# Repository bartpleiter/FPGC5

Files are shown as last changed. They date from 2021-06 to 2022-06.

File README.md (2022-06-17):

# FPGC5

My big project, basically started in July 2019 as FPGC3 (versions 1 and 2 do not count). Project exists to learn more about the fundamentals of computers and to improve my Verilog skills, while also designing my own "environment" (PCB, Compilers, OS, etc.) around it.

FPGC is a completely self designed computer, implemented in an EP4CE15 FPGA.

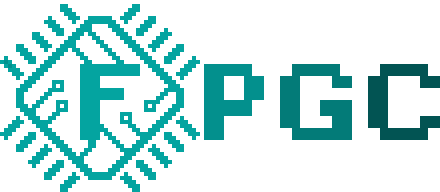
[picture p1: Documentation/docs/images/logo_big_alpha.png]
FPGC Logo (https://www.b4rt.nl/fpgc5/)


[Project Wiki](https://www.b4rt.nl/fpgc5/) (not fully up to date, but contains a lot of info)

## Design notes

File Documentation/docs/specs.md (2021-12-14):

# Specifications
These are the current specifications of the FPGC5:

- 50MHz CPU clock   
- 25MHz or 14MHz main GPU clock (depending on HDMI or NTSC being selected)
- 16MiB external SPI flash (QSPI with continous read mode) @ 25MHz. 32bit addresses (so not byte addressable!!!). Used as ROM, but has option to switch to direct access where it is connected to an SPI bus in the Memory Unit (allows for SPI flashing)
- 32MiB SDRAM @ 100MHz. 32bit addresses. Readable and writable. Used as main memory
- ~16.4KiB VRAM (SRAM). Combination of 32, 8 and 9bit addresses (three seperate modules for pixel data, tile indexes and sprites)
- 2KiB internal ROM for the Bootloader. 32bit addresses
- 4.125KiB Hardware Stack (SRAM). 32bit addresses
- 16 32bit registers, of which 15 are General Purpose
- 32bit instructions
- 27bit program counter for a possible address space of 0.5GiB at 32bit
- 320x200 video output (sent over 640x480 HDMI or 240P NTSC composite) with 256 colors
- Two layers of 8x8 Tiles of which one layer (background) has horizontal hardware scrolling support
- (currently not working anymore) One Sprite layer with support for 64 Sprites. Max 16 Sprites per horizontal line (double the amount of the NES!)
- Memory mapped I/O
- Three One Shot (OS) timers
- PS/2 Keyboard support
- UART and power over USB
- 4 GPI and 4 GPO pins (will become 8 true GPIO pins eventually)
- I2S DAC for future APU
- 2 USB host ports with FAT(12/16/32) file system support using a CH376T controller over SPI
- Ethernet using W5500 over SPI
- 8 interrupts, of which 4 normal interrupts (currently attached to two OS timers, UART RX and the frameDrawn signal of the FSX2), and 4 extended interrupts (currently attached to the PS/2 controller, a third OS timer and nothing for now)

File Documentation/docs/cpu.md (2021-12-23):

# CPU (B322)
The B322 (B4rt 32 bit processor v2) executes instructions from memory with the program counter as address. It is a 32 bit RISC CPU implementing the self designed B322 instruction set.

## B322 ISA
The B322 instruction set architecture is a RISC architecture.
Each instruction is 32 bits and can be one of the following instructions:
``` text
         |31|30|29|28|27|26|25|24|23|22|21|20|19|18|17|16|15|14|13|12|11|10|09|08|07|06|05|04|03|02|01|00|
----------------------------------------------------------------------------------------------------------
1 HALT     1  1  1  1| 1  1  1  1  1  1  1  1  1  1  1  1  1  1  1  1  1  1  1  1  1  1  1  1  1  1  1  1
2 READ     1  1  1  0||----------------16 BIT CONSTANT---------------||--A REG---| x  x |N||I||--D REG---|
3 WRITE    1  1  0  1||----------------16 BIT CONSTANT---------------||--A REG---||--B REG---| x  x  x |N|
4 COPY     1  1  0  0||----------------16 BIT CONSTANT---------------||--A REG---||--B REG---| x  x  x |N|
5 PUSH     1  0  1  1| x  x  x  x  x  x  x  x  x  x  x  x  x  x  x  x  x  x  x  x |--B REG---| x  x  x  x
6 POP      1  0  1  0| 0  0  0  x  x  x  x  x  x  x  x  x  x  x  x  x  x  x  x  x  x  x  x  x |--D REG---|
7 JUMP     1  0  0  1||--------------------------------27 BIT CONSTANT--------------------------------||O|
8 JUMPR    1  0  0  0||----------------16 BIT CONSTANT---------------| x  x  x  x |--B REG---| x  x  x |O|
9 LOAD     0  1  1  1||----------------16 BIT CONSTANT---------------| x  x  x |H| x  x  x  x |--D REG---|
10 BEQ     0  1  1  0||----------------16 BIT CONSTANT---------------||--A REG---||--B REG---| x  x  x  x
11 BNE     0  1  0  1||----------------16 BIT CONSTANT---------------||--A REG---||--B REG---| x  x  x  x
12 BGT     0  1  0  0||----------------16 BIT CONSTANT---------------||--A REG---||--B REG---| x  x  x  S
13 BGE     0  0  1  1||----------------16 BIT CONSTANT---------------||--A REG---||--B REG---| x  x  x  S
14 SAVPC   0  0  1  0| 0  0  0  x  x  x  x  x  x  x  x  x  x  x  x  x  x  x  x  x  x  x  x  x |--D REG---|
15 RETI    0  0  0  1| x  x  x  x  x  x  x  x  x  x  x  x  x  x  x  x  x  x  x  x  x  x  x  x  x  x  x  x
16 ARITH   0  0  0  0||C||--OPCODE--||--------11 BIT CONSTANT--------||--A REG---||--B REG---||--D REG---|
```

1.  `HALT`:   Will prevent the CPU to go to the next instruction by jumping to the same address. Can be interrupted.
2.  `READ`:   If !I, read from memory at address in AREG + 16 bit offset. If N == 1, then do - offset instead. If I, read interrupt ID. In both cases of I: store value in DREG.
3.  `WRITE`:  Write value from BREG to memory at address stored in AREG + 16 bit offset. If N == 1, then do - offset instead.
4.  `COPY`:   Read memory from address in AREG + 16 bit offset, then write result to memory at address in BREG + 16 bit offset. If N == 1, then do - offset instead.
7.  `PUSH`:   Pushes value in AREG to stack.
8.  `POP`:    Pops value from stack into DREG.
9.  `JUMP`:   Set PC to 27 bit constant if O is 0. If O is 1, then add the 27 bit constant to PC. 
9.  `JUMR`:   Set PC to DREG + 16 bit constant if O is 0. If O is 1, then add the value from DREG + 16 bit constant to PC. 
5.  `LOAD`:   Write 16 bit constant to DREG. If H is 0, then write data to lowest 16 bits and set highest 16 bits to 0. If H is 1, then write data to highest 16 bits and ignore lowest 16 bits.
11. `BEQ`:    If AREG == BREG, add 16 bit constant to PC.
12. `BNE`:    If AREG != BREG, add 16 bit constant to PC.
13. `BGT`:    If AREG >  BREG, add 16 bit constant to PC. Signed comparison if S.
14. `BGE`:    If AREG >= BREG, add 16 bit constant to PC. Signed comparison if S.
15. `SAVPC`:  Save current PC to DREG.
16. `RETI`:   Restore PC after interrupt and re-enable interrupts.
10. `ARITH`:  Execute operation specified by OPCODE on AREG and BREG. Write result to DREG. Use 11-bit constant in stead of BREG if C is 1.

## Components
The CPU consists out of the following components:

### Timer
Handles the timing of the CPU phases.

The Timer creates four phases for the CPU to execute each instruction:

1. fetch: Get instruction from memory
2. getRegs: Get register values from register bank
3. readMem: Read memory from address
4. writeBack: Write result back to register bank or memory and change the program counter

The fetch, readMem and writeBack phase can take multiple clock cycles because of the memory timings.

<figure>
    timer waveform
    <figcaption>Timer waveform. Running instructions from SDRAM (outdated simulation!).</figcaption>
</figure>

### Instruction Decoder
Splits the 32 bits of each instructions using combinational logic.
These parts are then connected to various other components of the CPU. 

### Register bank
Contains 16 registers which are all 32 bit wide. Aside from `R0` which is always zero, all registers are basically GP register. However, to maintain some kind of coding consistency, some registers have a special function assigned (though their hardware implementation are the same).

The 16 32 bit registers have the current functions:
``` text
Register|Hardware 	|Assembly	|C
-----------------------------------------------------
R0 		|Always 0	|Always 0	|Always 0
R1 		|GP			|Arg|retval |Very local temp reg
R2 		|GP			|Arg|retval |Ret0
R3 		|GP			|Arg|retval |Ret1
R4 		|GP			|GP			|Arg0
R5 		|GP			|GP			|Arg1
R6 		|GP			|GP			|Arg2
R7 		|GP			|GP			|Arg3
R8 		|GP			|GP			|GP0
R9 		|GP			|GP			|GP1
R10		|GP			|GP			|GP2
R11		|GP			|GP			|Temp
R12		|GP			|GP			|Temp
R13		|GP			|GP			|SP
R14		|GP			|GP			|BP
R15		|GP			|Ret Ptr 	|Ret addr
```
The register bank has two read ports and one write port. Internally on the FPGA, the registers are implemented as two block RAM modules to increase performance and save space. One module contains the highest 16 bits, the other the lowest 16 bits. This made it easy to implement the `LOADHI` instruction.

Note that the program counter is not part of the register bank, as it is a seperate part of the CPU.

### Stack
Stack memory with internal stack pointer. The stack is mostly used in assembly coding for jumping to functions and backing up or restoring registers in interrupt handlers or functions. In combination with the SavPC instruction, one can easily jump to (and return from) functions in assembly (C uses a software stack).

The pointer wraps around in case of a push when the stack is full or in case of a pop when the stack is empty.
The stack is 1024 words deep. The stack pointer and stack memory are not accessible by the rest of the CPU. This and the small size make the stack mostly unusable for the C compiler. For this, a software stack implementation using the 32MiB SDRAM main memory and R13,R14,R15 are used. However, the hardware stack is used to quickly backup and restore all 15 GP registers during an interrupt.

### ALU
Can execute 16 different operations on two 32 bit inputs. Has two flags, which are used for branch instructions. It also has an input flag `skip`. When set, the output of the ALU will just be input B. This is useful for writing values to a register after a `READ`.
The 4 bit opcode can specify the following operations:
``` text
Operation|Opcode|Description
-------------------------
OR        0000   A OR   B
AND       0001   A AND  B
XOR       0010   A XOR  B
ADD       0011   A  +   B
SUB       0100   A  -   B
SHIFTL    0101   A  <<  B
SHIFTR    0110   A  >>  B
MULT      0111   A  *   B (signed!)
NOTA      1000   ~A
```

The remaining seven Opcodes are reserved for future operations.

Internally, the CPU uses flags for executing the branch instructions. Depending on the instruction flags these comparisons can be signed. The flags are not readable by other instructions, because they are not saved in a register:
``` text
Flags
---------
BGA: B is greater than A
BEA: B is equal to A
```

### PC
Handles all program counter related functions like jumps and interrupts.

Every writeBack cycle, the PC is increased by one. In case of a jump, the PC is set to or increased by the jump address, based on the `O` flag of the jump instruction.

The CPU has 8 interrupt pins, of which 4 standard interrupts and 4 extended interrupts (extended has nothing to do with the duration of the interrupt, see it as a pin extension). When a rising edge on one of these pins is detected and interrupts are enabled, interrupts will be disabled, the PC value of the next instruction (this includes the destination address during a jump) will be stored and the set to the value of the interrupt pin (1, 2, 3, or 4, and 2 in case of an extended interrupt). When a RETI instruction is issued, the PC will be restored and interrupts re-enabled. Interrupts are only registered on the rising edge, to prevent the same interrupt from repeating itself when the handler is already done, but the signal is still high. In case of multiple interrupts at the same time, the lowest pin number has the highest priority. Interrupt 1 to 4 have priority over the extended interrupts. A flag for each rising interrupt is stored, even when interrupts are disabled. This causes the interrupt to be delayed until interrupts are enabled again. This way less interrupts are skipped.

For the extended interrupts, the PC will still jump to address 2, but will also set an ID. This way the interrupt handler can check which interrupt was triggered. The ID can be read using the `I` (interrupt) flag in the READ instruction.

### CU
The CU, or control unit, directs all signals to the corresponding components based on the instruction, state and flags. This is done using combinational logic.

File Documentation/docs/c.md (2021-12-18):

# C Compiler

!!! info "TODO"
	Very outdated! now using a C compiler based on SmallerC (written in C)

Using the C compiler it is possible to compile C code to B322 assembly. Using C it is way easier to write code for the FPGC5, although it is less optimized and currently not perfectly stable.

## How the C Compiler works
A C compiler is a very complex piece of software. To prevent having to spend a very long time on writing an instable, slow and unfinished C compiler, I modified an existing C compiler instead. I found a very good and well documented C compiler written in Python (the easiest programming language), called [ShivyC](https://github.com/ShivamSarodia/ShivyC). ShivyC outputs x86_64 assembly code. It has the following stages:

- lexer: reads C file, creates tokens
- preprocessor: handles include statements
- parser: parses tokens and creates an abstract syntax tree
- ILgen: generates Intermediate Language code from the AST
- ASMgen: generates x86_64 code from the IL

To make the compiler output B322 assembly, I (mostly) only needed to adjust the last stage. Luckily, the x86_64 assembly and B322 assembly have much in common in terms of registers and instructions (relatively), so no major modifications to the other stages, which were made with x86_64 in mind, were needed. Some assembly wrapping code is used to set up things like the stack, interrupt handlers and return code.

## Biggest differences between x86_64 and B322 assembly
There are a few big differences between these languages:

### Register sizes
B322 has 16 (15 if you ignore r0 which is always 0) 32 bit registers. x86_64 has multiple variants of its registers for 8, 16, 32 and 64 bit values. I 'fixed' this by forcing the C compiler to only use the 32 bit versions of the registers.

### Byte addressable memory
B322 uses word addressable memory, meaning that each address is 32 bits. x86_64 uses byte addressable memory, so I had to modify the compiler to use 1 address per integer (32 bits) instead of 4.

### Memory access in each instruction
B322 has READ, WRITE and COPY instruction to access memory. All other instructions can only be applied to registers (and in some cases literals). x86_64 can use literals, registers and memory (with offsets and multiplications!!!) for almost all instructions. This is by far the biggest problem I currently have and requires writing cases for almost all possibilities. I started doing this kind of ad hoc and need to spend more time on this to improve stability.

## Stack
C uses a stack. Since the hardware stack of the FPGC5 is too small, has no external pointers and is not addressable, a software stack is used instead. The stack starts at the end of SDRAM at 0x700000 and grows towards 0. The interrupt handlers have a separate (and smaller) stack, starting at 0x7B0000. R14 and R15 are used as base pointer and stack pointer respectively.

Since x86_64 has byte addressable memory, integers (32 bit) are stored with an offset of 4 of each other. The FPGC5 does not have byte addressable memory. This means that chars are stored in 32 bit spaces and therefore have no overflow. This also means that using variables longer that 32 bits (longs) are cutoff at 32 bits. Should not be a big issue, since we only have 27 bits addresses anyways. Worst case, this means that 75% of the stack is unused. While this sounds like a lot, it is currently not a problem because of the relatively huge memory size of 32MiB. Will probably fix it in the future.

## Register mapping
The registers are mapped in the following way:

``` text
x86_64 	| FPGC5
----------------
rax		| r1
rbx 	| r2
rcx 	| r3
rdx 	| r4
rsi 	| r5
rdi 	| r6
r8 		| r8
r9  	| r9
r10 	| r10
r11 	| r11
rbp 	| r14
rsp 	| r15
```
This leaves registers r7, r12 and r13 unused in the FPGC5.
r12 and r13 are currently used as temporary registers for certain assembly instructions, which is sometimes needed/convenient for converting single x86_64 instructions to multiple B322 instructions. For example, in x86_64 you can write a number to the stack at an offset using `mov [rbp-offset] 37`. In B322 you first need to load the literal into a register before using a write instruction. r7 is currently used as temp register for loading the address of global variables during for read/write instructions.

## Assembly wrapper
- Return value of Main() is sent over UART (mainly for testing)
- Initializes stack starting address
- Full context switch for interrupt handlers

## Testing the compiler
To make sure that everything still works after making a change in the compiler, I made a number of test .c files with an expected return value. Using the runCfiles.sh script, you can send compile and send multiple .c files to the FPGC5 and get their return value. So to automatically test all test files, you just have to run `runCfiles.sh test/*.c`. The script automatically compiles, assembles and sends the code over UART to the FPGC5 (so use the UART bootloader for the SPI flash module). When the program is done executing, the FPGC5 will send back the return value, which you can compare. The FPGC5 also resets between each file, because of the UART DTR reset (just like an Arduino).

## Supported and unsupported features
Most basic features like for/while loops are supported, so I will not list everything.

### Supported
- defines (only numbers, no expressions or strings)
- includes (.h files should also contain the code, because no linking). Circular dependencies are allowed. Defines from includes carry over, like real C
- inline assembly (see section inline assembly)
- structs (not fully tested)
- arrays
- pointers
- hex and binary numbers (using 0x and 0b prefixes), also in defines
- bitwise operators (shift, xor, etc.) (bitwise and uses `&&&` as sign!)
- probably some things that I don't use, see ShivyC on Github.

### Unsupported
- floating points
- negative numbers! (the FPGC5 does not do any signed operations)
- division and modulo (use div() and mod() in the math library for this)
- include guards, since this is handled internally inside the compiler (for includes)
- compiling and linking multiple .c files. So libraries should be written entirely in a single .h file
- certain array initializers (like `char a[] = "foo";`)
- complex things like varargs, which I never used anyways
- probably some other things :s

## Interrupt handler
Because of the way interrupts are handled in the assembler, it is required for each main .c file to have the functions (void) int1() int2() int3() and int4(). These can be empty, since the context switch (using the hardware stack) and `reti` are handled by the wrapper.

## Inline assembly
The C compiler supports inline B332 assembly. See the following code for an example:

``` c
int main() 
{
	int a = 7; // should be put into r1 by the compiler

	// backslashes are needed for the lexer, semicolons are needed to keep track of each line
	// comments can be added before the semicolon using //
	ASM("\
		load 4 r2								;\
		add r1 r2 r3 	//adding two regs		;\
		sub r3 1 r1 	//remove one to get 10 	;\
		");

	return a; // should now be 10
}
```
Inline assembly is especially useful for implementing fast functions like copying VRAM tables. It might also be useful for addressing I/O, though this will depend on the situation, since you cannot easily access values from the C code using assembly.

!!! danger
    The compiler does not parse the assembly code, so be very very careful to not mess up the registers. Use `pop` and `push` to back them up!

## Coding style recommendation
Since there is currently no OS, memory (heap) management needs to be done by the programmer. So write at top of program/library which variables are stored at which address. Also, see the Main Memory Map below.

- Some variables can be defined as global variables, which the compiler puts in the Program code (recommended way if possible)
- Libraries have their own heap, and each library should use different addresses within this space
- Use clear function names, and defines with prefixes if necessary, to avoid conflicts
- Use integers for pointers, as they are 32 bit
- Use mostly integers, since these are the same size as a register
- Program code is not different from any other place in memory, and therefore can be easily modified at runtime

### Main Memory Map
This memory map visualizes where what is (or should) be stored where in memory:

``` text
|00|01|02|03|04|05|06|07|08|09|10|11|12|13|14|15|16|17|18|19|20|21|22|23|24|25|26|27|28|29|30|31|
|_______________________________________________________________________________________________|
|-----------------Program Code------------------|Usr Heap|L*|---------Stack---------|Int S*|-R*-|
					 16MiB						   3MiB  1MiB          8MiB         2.75MiB 1.25MiB

L* 		= Library heap, like a map with the currently pressed ps/2 buttons
Int S* 	= Interrupt stack, a separate stack for interrupt handlers
R* 		= Currently unused, reserved for future things

```

## NOTES

Notes that came up while working on BCC:
- the goal of this C compiler is to write code for the FPGC, not to be compliant to anything C related!
- should probably use chars as much as possible, since they are 32 bits in my case and the compiler will align this with memory (might want to typedef tho)
- should optimize the reimplementation of BDOS as much as possible now I have the chance

- includes:
    - all includes should be .c files, there is no linker and everything should be considered as one big C file
    - because no linking and .h files, only the main.c file should include all libraries, so libraries should not include files themselves (main.c should do that for them)
       Might want to add in comments which includes the library needs
    - if there are two functions that call each other (or some kind of loop), you should be able to just add a template function at the top (like a header file does)
    - global variables accessed by libraries should be defined above the #include

- ASM:
    - use this:
    ``` text
    // r2 contains the return value, r4 contains the argument
    int asmReturn(int x)
    {
        int retval = 0;

        asm("load 4 r3\n"
            "add r4 r3 r2    ;adding two regs\n"
            "sub r2 1 r2     ;remove one to get 10\n"
            "write -4 r14 r2 ;write to stack to return");

        return retval;
    }
    ```

- comparison is signed by default. For unsigned comparison, cast both expressions to (unsigned int) -> forces bge/bgt instead of bges/bgts

- could optimize for speed by converting more basic functions to ASM
    - also, the ch376 asm functions could use a COPY instruction instead of a read followed by write

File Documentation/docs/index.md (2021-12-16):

# Welcome to the FPGC Wiki!

FPGC Logo (https://www.github.com/b4rt-dev/fpgc5)

!!! danger
    A lot of the documentation is probably outdated

For more details, use the navigation menu.

## What it is
The FPGC5 (Field Programmable Game Console/Computer v5) is my big hobby project, built around a completely self designed SoC (System on a Chip) with my own CPU, GPU and Memory Unit, all implemented on an FPGA. The goal of this project is to understand how computers actually work, by making one myself. This is achieved by starting from scratch and adding a layer of complexity iteratively. As of writing it has a simple OS and C compiler.

Originally, the goal of this project, which started in 2017 when I bought my first FPGA, was to design a simple game console for an FPGA (hence the name FPGC). Eventually this idea shifted more towards creating an entire computer with the capabilities of a game console. Now this is shifting even more to a computer rather than game console (the third PCB doesn't even have a game controller connector anymore).

To give a general idea: The FPGC is kind of a Raspberry Pi, but with the performance of a Commodore 64, the graphics of a NES, and some "less retro" features like HDMI, USB host, Ethernet, 32MiB SDRAM and a 32 bit architecture.

The main components of the FPGC5 consist of my 32 bit CPU (B322), my tile/sprite based GPU (FSX3) and my Memory Unit (MU) that handles many different types of memory and I/O. No audio engine yet, though I do have an I2S DAC on the PCB.

Aside from the FPGA hardware, this project also contains other software projects built for the FPGC, like an assembler, C compiler (both cross-compile from Linux and self compile from BDOS), Operating System (BDOS), software libraries, programmer, example code like a webserver and a wget implementation, and more.

For this project I also designed an I/O board PCB.

## What it can do
Basically, the FPGC5 can run code, compute things, play games, output video (over NTSC or HDMI), and can interact with certain peripherals using for example GPIO, SPI or UART. It also has two USB host port for mass storage (required for BDOS) and something else, a PS/2 port for a keyboard (although an USB keyboard can also be used) and an Ethernet port for networking. It has 32MiB SDRAM and the program code is very quickly loaded from SPI flash or USB UART into SDRAM on boot. The board is powered from a single micro USB port, with UART capabilities for in-system programming.

As for performance, you should think of a computer from the 80's, but with 32MiB SDRAM, multiple gigabytes of (slow, you want to use buffers) mass storage using USB, and a (not so efficient) 32 bit CPU running at 50MHz. The GPU creates a 320x200 video output which is currently sent over a 640x480 HDMI signal and a composite NTSC signal for my CRT TV (output can be selected using a switch). The graphics are comparable to a NES (currently sprites need to be reimplemented for the HDMI/Composite output).

## Project hardware and software
The target FPGA is an Altera Cyclone IV EP4CE15 (the EP4CE6 has too little I/O, memory and logic gates). The development board used in this project is the [Cyclone IV EP4CE15 Core Board with 32MiB SDRAM from QMtech](https://www.aliexpress.com/i/32949281189.html). This board is plugged into my I/O board PCB, which provides all I/O and power.

All hardware designs are written in Verilog. Iverilog and GTKwave are used to simulate these hardware designs before writing the design to the FPGA using Quartus Prime (Lite).

Most scripts are written in Python 3 (or bash for some simple tasks), except for the C compiler, which is written in C. The cross-assembler is written in Python, and an assembler written in C is being made to run on BDOS. The assembler assembles a self designed assembly language, and the C compiler compiles C to this assembly language.

Sublime Text 3 is used as text editor/IDE, with some handy build scripts to speed up the development and to quickly send code to the FPGC.

There are also scripts that allow sending files and programs directly to BDOS over the network.

## Structure of project files
The general structure of this project:
``` text
FPGC5
├── Assembler           // Assembler (in Python) and assembly code files
├── BCC                 // C compiler project, also contains programs and OS
├── Documentation       // Documentation website project
├── Graphics            // Scripts for graphics related stuff
├── MidiConverter       // Scripts to convert .mid files into audio asm code
├── PCB                 // PCB KiCad source files
├── Programmer          // Scripts for programming the FPGC5
├── Quartus             // Quartus project files
├── SublimeText3        // Project build scripts for Sublime Text 3
└── Verilog             // Verilog source files
    ├── memory          // Memory init related files
    ├── modules         // Hardware modules
    ├── output          // Simulation output
    └── testbench       // Simulation testbench
```

## Project Links
- [Github Repository](https://www.github.com/b4rt-dev/FPGC5)
- [Gogs Mirror](https://www.b4rt.nl/git/bart/FPGC5-mirror)
- [Documentation (this site)](https://www.b4rt.nl/fpgc)

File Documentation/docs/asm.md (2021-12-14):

# Assembler for B322

!!! info
    This is both outdated (no .code/.data/.rdata/.bss, no --bdos or --os, etc.) and only applies to the cross-assembler written in Python!

The basic way to write code for the B322 is by using the B322 assembly language. Using the assembly language you can write the most optimal code, although it might not be the best way for big or complex programs. For high performance functions like copying VRAM tables, assembly is a good solution. For big and complex software, it is better to write the code in C. The C compiler compiles to this assembly language.

The assembler compiles the assembly code to 32 bit machine instructions. The input file is currently code.asm, and the output is printed to stdout.

## Line types
Each line is parsed on its own. There are five types of lines:

- Includes
- Comments
- Defines
- Labels
- Instructions

### Includes
By adding an \`include namehere.asm statement, it is possible to add code from other files, like libraries. The way this works in the assembler is by just adding all lines of that file to the code, while recursively importing includes from other files. The assembler makes sure that the same file is never included more than one time. The path to the file is relative to the assembler.

### Comments
Comments can be added by using the ';' character. For each line, only the part until the first ';' occurrence will be used by the assembler. This means that anything can be written after the ';'. This all does not go for .ds lines. They must not have any comments. This way it is not needed to use escape characters in the strings

### Defines
Defines are the first type of lines that are processed by the assembler. A define line should have the following structure:
``` asm
define TEXTTOREPLACE = textToReplaceWith
```
It is not necessary for 'define' to be in lower caps and 'TEXTTOREPLACE' to be in all caps. However, it is recommended to do so as a coding style. Also, it is recommended to place all define statements at the top of the file before the first instruction or label.
The define statement is used as a textual replacement. This means that no values or anything will be processed or converted during the processing of the define statements. This also means that is not smart to replace text that are used in instructions or labels.
Furthermore, 'TEXTTOREPLACE' should be unique for each define statement. If not, the assembler will complain.

### Labels
Labels can be used to get the address in the assembled code of the instruction below the label. To define a label, one should use the following syntax:
``` asm
LabelName:
```
LabelName can consist of any character, including numbers and special characters, as long as it is just one word (so no spaces, newlines etc.) The label must end with a ':' character. On the same line after this ':' character, no other text is allowed, except comments.

A label can be referenced by using the LabelName in certain instructions at specific places (see section Instructions).
The assembler will eventually compute the address of the label and replace all LabelName occurrences with this address. One can make forward and backward references, which means that one does not have to define a label earlier in the code before referencing, as long as the label is defined somewhere in the code.

Each program should at least contain the following labels (if not, the assembler will complain):
``` asm
Main: ; this is where the CPU will initially jump to
Int1: ; interrupt 1 handler
Int2: ; interrupt 2 handler
Int3: ; interrupt 3 handler
Int4: ; interrupt 4 handler
```

It is recommended to start each label with a capital letter, however this is not mandatory.
One should not use two labels directly after each other without any instruction in between (the compiler will now insert a NOP in between the labels if this happens, since the C compiler sometimes creates this issue), and one should not use a label at the end of the file. The assembler will complain if the latter happens.
When two identical labels are defined, the assembler will complain.
It does not matter if a label is never referenced.
However, it does matter when a reference is made to a label that is not defined. In that case the assembler will complain.
Each of the interrupt handler labels should 'end' with a reti instruction, otherwise the CPU will not return from the interrupt and could highly probably softlock. However, this is not checked by the assembler.

### Instructions
The instructions are the lines that will be assembled into machine code. Each instruction has its own format with the following description:
``` text
Instr   | Arg1  | Arg2 | Arg3   || Description
================================||=====================================================================
HALT    |       |       |       || Halts CPU by jumping to the current address
READ    | C16   | R     | R     || Read from addr in Arg2 with 16 bit offset*** from Arg1. Write to Arg3
WRITE   | C16   | R     | R     || Write to addr in Arg2 with 16 bit offset*** from Arg1. Data to write is in Arg3
COPY    | C16   | R     | R     || Copy from address in Arg2 to addr in Arg3 with 16 bit offset*** from Arg1
PUSH    | R     |       |       || Push Arg1 to stack
POP     | R     |       |       || Pop from stack to Arg1
JUMP    | L/C27 |       |       || Jump to Label or 27 bit constant in Arg1
JUMPO   | C27   |       |       || Jump to 27 bit constant offset in Arg1
JUMPR   | C16   | R     |       || Jump to Arg2 with 16 bit offset in Arg1
JUMPRO  | C16   | R     |       || Jump to offset in Arg2 with 16 bit offset in Arg1
LOAD    | C16   | R     |       || Load 16 bit constant from Arg1 into Arg2
LOADHI  | C16   | R     |       || Load 16 bit constant from Arg1 into highest 16 bits of Arg2
BEQ     | R     | R     | C16   || If Arg1 == Arg2, jump to 16 bit offset in Arg3
BNE     | R     | R     | C16   || If Arg1 != Arg2, jump to 16 bit offset in Arg3
BGT     | R     | R     | C16   || If Arg1 >  Arg2, jump to 16 bit offset in Arg3
BGE     | R     | R     | C16   || If Arg1 >= Arg2, jump to 16 bit offset in Arg3
BGTS    | R     | R     | C16   || (signed) If Arg1 >  Arg2, jump to 16 bit offset in Arg3
BGES    | R     | R     | C16   || (signed) If Arg1 >= Arg2, jump to 16 bit offset in Arg3
SAVPC   | R     |       |       || Save program counter to Arg1
RETI    |       |       |       || Return from interrupt
OR      | R     | C11/R | R     || Compute Arg1 OR  Arg2, write result to Arg3
AND     | R     | C11/R | R     || Compute Arg1 AND Arg2, write result to Arg3
XOR     | R     | C11/R | R     || Compute Arg1 XOR Arg2, write result to Arg3
ADD     | R     | C11/R | R     || Compute Arg1 +   Arg2, write result to Arg3
SUB     | R     | C11/R | R     || Compute Arg1 -   Arg2, write result to Arg3
SHIFTL  | R     | C11/R | R     || Compute Arg1 <<  Arg2, write result to Arg3
SHIFTR  | R     | C11/R | R     || Compute Arg1 >>  Arg2, write result to Arg3
MULT    | R     | C11/R | R     || Compute Arg1 *   Arg2, write result to Arg3
NOT     | C11/R | R     |       || Compute NOT Arg1, write result to Arg2
NOP     |       |       |       || Does nothing, is converted to the instruction OR r0 r0 r0
ADDR2REG| L     | R     |       || Loads address from Arg1 to Arg2. Is converted into LOAD and LOADHI
READINTID| R    |       |       || Reads the interrupt ID from memory to Arg1 by setting the I flag in a READ instruction
.DW     | N32   | *     | *     || Data: Each argument is converted to 32bit binary
.DD     | N16   | *     | *     || Data: Each argument is converted to 16bit binary **
.DB     | N8    | *     | *     || Data: Each argument is converted to 8bit binary **
.DS     | N8    | S     |       || Data: Each character of the string is converted to 8bit ASCII **

/   = Or
R   = Register
Cx  = Constant that fits within x bits
L   = Label
S   = String

*  Optional argument with same type as Arg1. Has 'no limit' on number of arguments
** Data is placed after each other to make blocks of 32 bits. If a block cannot be made, it will be padded by zeros
*** Offset can be negative as well. This is useful for the C compiler
```

Each Cx type argument (constant) can be written in decimal, binary (with 0b prefix) or hex (with 0x prefix).

The assembler creates the first six lines of the program, since these are always the same instructions plus the length of the program:
``` text
Jump Main
Jump Int1
Jump Int2
Jump Int3
Jump Int4
[Length of program]
```

## Assembling process
The assembler does the following things the the following order:

1. Remove all comments, while reading the input file line by line
2. Process the define statements
3. Compile all lines that can directly be compiled (so without labels)
4. Create new lines for instructions that become multiple lines
5. Process all labels
6. Recompile the lines that had a label before
8. calculate and write program length
7. Write result to output file

### Input and output files
Currently one cannot pass arguments to the assembler. The assembler will read the code from code.asm and write the result to stdout. I might add file handling in the future.

## Important notes
One important assumption is that the code will be executed from addr 0 of the SDRAM. Otherwise the label addresses will not be calculated correctly. In the future I might add an offset argument where all labels are offsetted by this argument, and a flag to disable the required Interrupt handlers, though these features have no use right now and therefore no priority.

## Other things
I could create my own syntax highlighting for Sublime Text 3, however its Z80 syntax highlighting is already kinda decent. Might modify it in the future to support my assembly instead.

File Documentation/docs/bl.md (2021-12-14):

# Bootloader code
The bootloader, located at the first address of the internal ROM (see memory map for the address), is the first thing that is executed by the CPU, even though it is not located at address 0. The bootloader is used to copy a program from the relatively slow SPI flash to the faster SDRAM, or to copy a UART bootloader in SDRAM to allow for a program to be sent over UART. In either case, the bootloader ends with jumping to SDRAM address 0 after clearing all registers to 0, which starts the program or UART bootloader. Since the bootloader has room for 512 words (32 bit), a POST test has been added as well. This means that at the start of the bootloader, the FPGC logo is printed on the display in the color white. When the bootloader is almost done (just before clearing the registers and jumping to address 0), the color is changed to blue/green as indication that the bootloader has finished.

There are two modes for the bootloader:
- If the first slider of the DIP switch is positioned down, then the bootloader will copy the UART bootloader, which is stored in the ROM as well, to SDRAM.
- If the first slider of the DIP switch is positioned up, then the bootloader will copy X addresses, where X is the number in (32 bit) address 5 of the SPI flash.

All registers are reset before jumping to address 0, because the UARTbootloader has to halt in the first instruction and therefore has to assume all registers are empty (hard to explain, see UART bootloader code).

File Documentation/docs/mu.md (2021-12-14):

# MU

The MU, or memory unit, handles all memory access between the CPU and all the different memories used in the FPGC. The MU makes use of a memory map (see the Memory map page) so it knows from or to which memory it should read or write. The MU contains logic for reading and/or writing each type of memory that is connected to the MU. The goal of the MU is to have the CPU access all memories without the having to care about the type or timing of the memory, making an easy memory interface for the CPU. This is achieved using a bus protocol, which does add a cycle of overhead in most cases.

<figure>
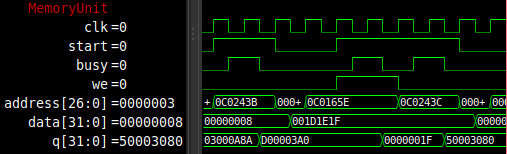
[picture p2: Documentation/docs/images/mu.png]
Memory Unit waveform
    
    <figcaption>MU waveform. Fetching instructions from ROM, writing to VRAM.</figcaption>
</figure>

The MU is connected to the following memories:

## SPI flash
The SPI flash is mostly used to contain a program (or second bootloader), since this allows the FPGC to run a program on its own without the need to have it sent over using UART. The size of the flash currently in use is 16MiB, and can be read completely by the MU. The MU makes use of an SPI flash controller which accesses the flash chip in quad SPI mode with continuous reading for faster reads. The maximum speed without modifying the amount of dummy clocks for each read is 25MHz, which is currently the speed of most of the FPGC, which is very convenient. Because of the SPI interface (which is serial), it takes many cycles to read one 32 bit instruction. Therefore, the contents are usually copied to the faster SDRAM by the bootloader, though it is possible to directly execute from SPI flash. While the SPI flash chip uses 8 bit addresses internally, the controller can be addressed by 32 bit words. The values of 'empty' addresses are all ones.

For this SPI flash controller only read instructions are implemented, so no writing or erasing is possible. However, it is also possible to switch to a direct SPI bus mode. When a special register in the MU is written (see memory map), the SPI flash will be accessible using a generic SPI interface. This allows the CPU to send and receive SPI commands in single SPI mode. While this is much slower, it gives the CPU full control over the chip, allowing for reprogramming and such.

To test the timing and functionality of the SPI flash controller, I added a simulation model of the W25Q128JV SPI chip (from the WinBond website), which is compatible with the W25Q128 I use in hardware. The SPI flash controller reads from this chip when a trigger occurs. When done reading it sets the recvDone signal high. Before all of this can happen, the chip has to be initialized. This is done by sending a 'reset continuous reading' command and a read command with the continuous reading bits set. This way each read does not have to start with an 8 cycle instruction. After initialization, the initDone signal is set high. When the MU gets a request from the CPU to read from SPI flash while the chip is not initialized yet, then the MU will wait (by keeping the busy signal high) until initialization is done before reading.

## SDRAM
The SDRAM is used as the main memory for the FPGC. It has a size of 32MiB. Since it is SDRAM, it requires a controller that handles all access and refreshes. The MU contains such controller to interface with the SDRAM. During initialization, the chip is set to a CAS latency of 2 and a programmable burst length of 2 (since we have 32 bit words, and the chip uses 16 bit data). The controller also handles refreshes. To reduce the amount of latency, the MU sets its busy flag low right after the read data is available or the written data is sent to the SDRAM chip. This way the CPU does not have to wait for row closing operations to be performed. If the MU gets a request from the CPU to read from or write to SDRAM, while the SDRAM controller is busy (for example with a refresh or row closing operations), then the MU will wait until the SDRAM controller is ready. While the SDRAM chip uses 16 bit addresses internally, the controller is addressed by 32 bit words. The data of the SDRAM at power up is undefined, but probably zero. Note that during a reset (soft or hard) of the FPGC, the contents of the SDRAM will stay. To clear the contents of the SDRAM, you can either write all addresses with zeros, or power down the FPGC for several seconds.

The first addresses of the SDRAM contain the program copied from SPI flash by the bootloader. I also added a simulation model of the SDRAM to the project. The currently used SDRAM chip is the Winbond W9825G6KH-6 (an older revision of the FPGA development board uses the Micron MT48LC16M16A2 chip. I originally started with this chip and it also works. The Verilog SDRAM simulation model is a model of the Micron chip).

## ROM
Internally on the FPGA, 2KiB of SRAM/Block RAM is used as ROM (it is initialized by the FPGA and unwritable when the FPGA is configured). It contains the bootloader of the FPGC, see the bootloader section for more details. This code is read only and can only be modified by reprogramming the FPGA.

## VRAM32
VRAM32 is the 32 bit wide dual port dual clock video RAM (SRAM/Block RAM) used by the CPU and the GPU. It contains the pattern table and palette table for the GPU. It is implemented using internal SRAM/Block RAM. There are two VRAM32 modules in use at the same time (the contents are duplicated), allowing the Background/Window and Sprite rendering part of GPU to access the memory at the same time. This greatly reduces the complexity of the GPU while only slightly increasing the block RAM usage.
The values of this memory at power up are all zero.

## VRAM8
VRAM8 is the 8 bit wide dual port dual clock video RAM (SRAM/Block RAM) used by the CPU and the GPU. It contains the background tile table, background color table, window tile table and window color table for the GPU. It is implemented using internal SRAM/Block RAM. The final two addresses are the horizontal tile offset and horizontal pixel offset for scrolling. Originally the resolution was 320x240 instead of 320x200, so there are certain unused addresses.
The values of this memory at power up are all zero.

## SpriteVRAM
SpriteVRAM is the 9 bit wide dual port dual clock video RAM (SRAM/Block RAM) used by the CPU and the GPU. It contains the sprite table for the GPU. It is implemented using internal SRAM/Block RAM. The memory has room for 64 sprites, where each sprite as a separate address for X position, Y position, tile index and color index+flags.
The values of this memory at power up are all zero.

## I/O
All other I/O devices are mapped to the I/O memory block (see Memory map). The following list describes the currently attached I/O devices.

### PS/2 Keyboard
A PS/2 Keyboard reader. Throws an interrupt when a scan code is received. The scan code can then be read from memory. A software library is required to keep track of which button is pressed. Read only, so it is not possible to set the lights on the keyboard.

### OStimer
The OStimer (one stop timer) can be used to generate an interrupt after a programmable amount of time. Each timer has two memory addresses. One address specifies the time in milliseconds by using a prescaler of 25000 (which gives 1 millisecond), the other address acts as a trigger if it is written to (it does not matter what value). An interrupt is raised for 16 clock cycles after the countdown has finished. An OStimer is used for all delay functions in C, and is very useful for music playback.

### UART
Using the addresses mapped to the UART RX and UART TX modules, it is possible to communicate with devices like a PC using UART. The baud rate is always set to 1MBaud and cannot be changed without modifying the FPGA design. When a byte is received, an interrupt is triggered and the byte can be read from a certain address.

### SPI
The SPI module allows for hardware SPI communication, removing the need for bit-banging using GPIO. The chip select pin is not part of this module and should be used by writing to a seperate memory address so transferring multiple bytes per SPI transfer is possible. The FPGC currently contains three of five SPI modules: One for the SPI flash, two for the CH376T chips, one for the W5500 chip and one for the extension port. Most SPI modules run on 25MHz, except for the CH376T, since these cannot handle such speeds.

#### CH376
Using the CH376T USB controller chip over SPI, it is relatively really simple to read and write files to an USB stick with a FAT or FAT32 partition table. It is also possible to do other things, like reading USB MIDI keyboards and HID devices, although a bit more difficult because of the lack of (English) documentation on the chip. I have working code for polling a USB keyboard. The n_interrupt pin from the CH376 is also accessible from the memory map, which makes getting status codes a lot easier.

!!! info "Note:"
	The "Set file name" command cannot handle input data with more than 14 characters (excluding terminator?), so to open a file in a subdirectory you need to send the directory name and use "File open" first before sending the filename itself. All filenames should be CAPITAL LETTERS ONLY, following the old 8.3 file name format. Also, the chip can be a bit unreliable when the flash drive is 'incorrectly' formatted. I know it works for FAT32 with a cluster size of 2KB.

#### W5500
The Wiznet W5500 is used for Ethernet. It is connected to one of the SPI modules of the MU. It has 8 sockets and contains hardware for the most used protocols like TCP, UDP and ICMP, making it very easy to use. Currently the interrupt pin is not used.

### GPIO
One address on the Memory map is mapped to GPIO pins on the FPGC. Only the right 16 bits are used. The left 8 of these 16 bits are read only and are the state of the 8 input ports. The right 8 of these 16 bits are the state of the 8 output ports. The output ports can written and read. I will eventually work on this module to make it true GPIO, using tri-states and programmable input/output mode. Currently only 4 pins of each are mapped to the 8 physical pins of the new PCB design.

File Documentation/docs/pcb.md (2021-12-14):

# I/O Board

!!! info "TODO"
	Very very outdated, PCBv3 is already done!

I have designed an I/O wing for the FPGA development board, as a replacement for the cardboard box where I used to glue everything in. The PCB was designed using KiCad and manufactured by JLCPCB. The KiCad project files (including schematic, PCB and 3D models) are in the PCB folder.

## Design choices
During the development of the PCB, many design choices had to be made, which I will explain here.

### Layout
I wanted to keep the PCB as small as possible, for practical and aesthetic reasons. The most practical way to do this was placing the core board on top and using all four sides of the PCB for I/O. I tried to place all the I/O on a logical position, so (diagonally) video, audio and power on one side, and buttons, controllers, LEDs and headers on the other side. I placed the most used I/O on the front, which are the buttons and controllers. The nConfig button of the FPGA is also routed (using a wire from resistor R244 to J10 on the PCB) to a button on the front. The DC jack on the core board does not have to be used anymore, only the JTAG interface is needed when the FPGA design needs to be changed. Finally, I opted for a black/white design, since it matches the core board.

### Components
For the video DACs, I chose the GM713C (a clone of the ADV7123), since these are very cheap and very good (10 bits per color, can handle 1080P @60FPS without problem). Since this project only uses 8 bits for all colors, instead of 30 bits, it looks like it is a bit overkill. The alternative would be a resistor DAC, but that would put more load on the I/O of the FPGA (while terminating with 75 ohm) and does not protect the FPGA from ESD that well (I am not an expert on ESD, but using a dedicated chip seems a lot safer to me). 

As for the audio DAC, I did choose to just use some resistors and DC removing capacitor, since the audio just consists of simple square waves (no PWM). While this heavily limits the audio the FPGC5 can produce, it can still play some cool polyphonic tunes. I decided to not go for a 'real' DAC, because this project is not about audio development. The components in the audio DAC can be replaced to act as a low pass filter, which would allow PWM audio if I ever decide to do audio development on this board. Alternatively, it is also possible to add a I2S DAC (or any other DAC) on the bottom of the PCB. The audio signal is also routed to the DSUB9 (video) connector to get audio from the CRT TV without extra cables.

The entire board is powered from one mini USB port, which also is connected to an FT232RL. This way you only need one USB cable which you can plug into your PC to power the entire board and to communicate with it. I could have opted for a cheaper Chinese chip, but the FT232RL is just a really solid chip with good driver support, and does not cost that much either.

The final big component decision was the USB controller. Before having a PCB, I used the CH376S over SPI. This chip does all the complicated USB stuff and is specialized for USB mass storage. It even handles all the file system stuff. This allows me to easily add non-volatile mass storage to the FPGC5 without having to spend months on implementing all the complicated USB and file system stacks. While the documentation of the chip is pretty bad, I was still able to read other simple USB devices using this chip (with an Arduino) like a USB mouse and USB MIDI keyboard. So using this chip over something like a MAX3421E was an easy choice. The CH376S is pretty bulky, but luckily there is a smaller variant without 8-bit parallel interface that is called the CH376T. I think a CH375 or something should also work (since I do not use the SDcard controller that is added in the CH376), but I could not find that chip for sale anymore.

## Component buy list
List of the important components and where I bought them

- [MF-MSMF050-2 1812 SMB PPTC 500mA fuses](https://www.aliexpress.com/item/Free-shipping-20PCS-MF-MSMF050-2-1812-SMD-PPTC-15V-0-5A-500mA-7905-resettable-fuses/32899546296.html)
- [PS/2 Sockets](https://www.aliexpress.com/item/5pcs-PS2-socket-PS-2-socket-6P-PS-2-keyboard-mouse-holder-socket-outlet/32847566873.html)
- [0805 Capacitor kit](https://www.aliexpress.com/item/MCIGICM-0805-SMD-Capacitor-assorted-kit-36values-20pcs-720pcs-1pF-10uF-Samples-kit-electronic-diy-kit/33011427492.html)
- [0805 Resistor kit](https://www.aliexpress.com/item/33valuesX-20pcs-660pcs-0603-0805-1206-Resistor-Kit-Assorted-1R-to-1M-ohm-1-SMD-Sample/33029877427.html)
- [0805 510 + 75 Ohm resistors](https://www.aliexpress.com/item/100pcs-0805-5-1-8W-SMD-chip-resistor-0R-10M-0-1R-10R-100R-220R-330R/32865947306.html)
- [BSS138 Power Mosfets](https://www.aliexpress.com/item/100pcs-lot-BSS138-BSS138LT1G-J1-SOT23-5-Power-MOSFET/32770656298.html)
- [Tactile push buttons](https://www.aliexpress.com/item/50Pcs-DIP-6-6-7mm-Tactile-Tact-Push-Button-Micro-Switch-Momentary-Vertical-Push/32710764066.html)
- [FT232RL](https://www.aliexpress.com/item/IC-Chips-FT232RL-FT232R-FT232-USB-to-Serial-UART-28-SSOP-Original-Integrated-Circuits-for-Arduino/33021952216.html)
- [HC-49S Crystal kit](https://www.aliexpress.com/item/hc-49s-Crystal-Oscillator-electronic-Kit-resonator-ceramic-quartz-resonator-hc-49-DIP-7-kinds-X/32844442076.html)
- [0805 LED kit](https://www.aliexpress.com/item/100pcs-lot-5-Colors-SMD-0805-Led-DIY-kit-Ultra-Bright-Red-Green-Blue-Yellow-White/32888607342.html)
- [GM7123C](https://www.aliexpress.com/item/1pcs-lot-GM7123C-GM7123-LQFP-48/4000120297839.html)
- [CH376T](https://www.aliexpress.com/item/Brand-new-original-CH376-CH376T-SSOP20-quality-assurance/32955964901.html)
- [QMTECH EP4CE15 Core board](https://www.aliexpress.com/item/QMTECH-Altera-Intel-FPGA-Core-Board-Cyclone-IV-CycloneIV-EP4CE15-SDRAM-Development-Board/32949281189.html)
- [PCB](https://jlcpcb.com/)
- SNES controller connector (I already had from Aliexpress. Now there is also a black version, which I recommend over the gray version)
- USB female connectors, mini and full size (both scavenged from old hardware)
- Other things like the power switch, headers, big capacitors and audio jack (which I had already bought before)

## Cost
The PCB (or actually five of them) was made by JLCPCB for 7.44 Euro. Shipping to the Netherlands was 8.55 Euro.
The FPGA core board including shipping was about 20 Euro.
All other components (that I did not already have at home) including shipping did cost me 25 Euro.
So the entire project did cost me about 60 Euro.

## Pictures

### PCB

#### KiCad design

The PCB is designed in KiCad.

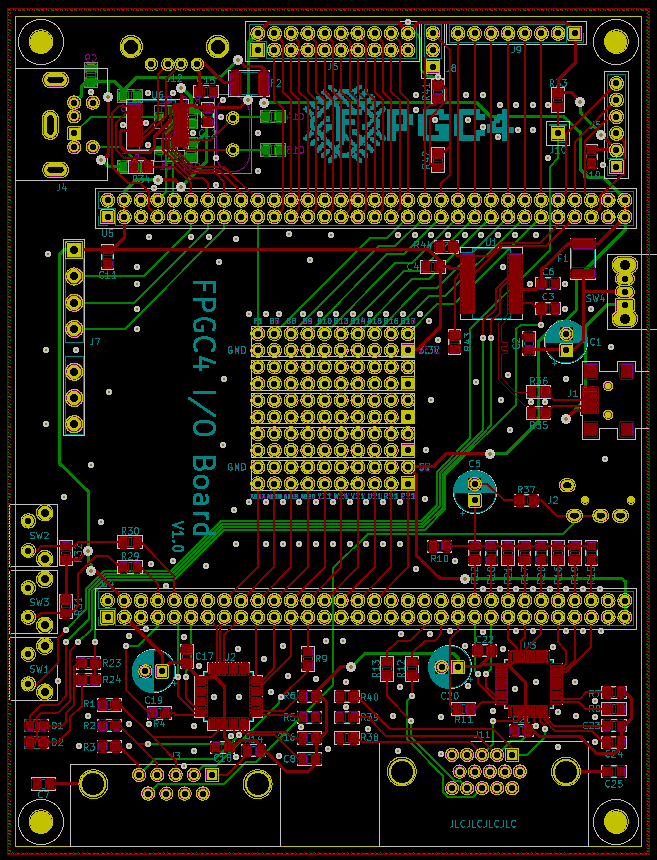
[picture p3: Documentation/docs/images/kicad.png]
kicad


#### Manufactured

The result after sending the design to JLCPCB.

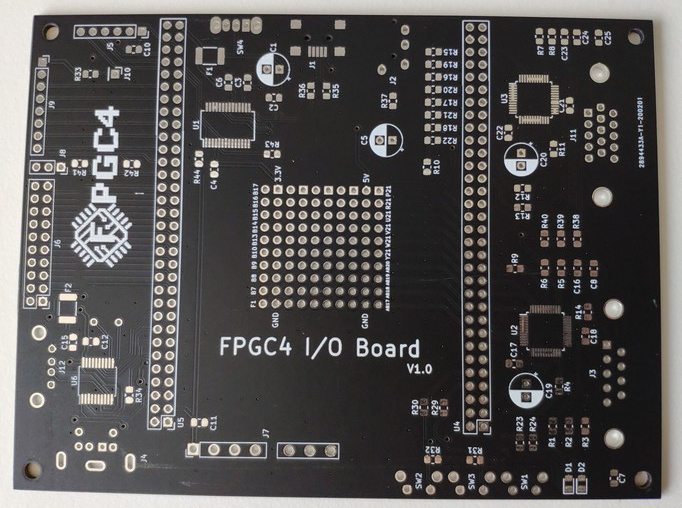
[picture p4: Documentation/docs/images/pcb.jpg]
pcb


#### Top view

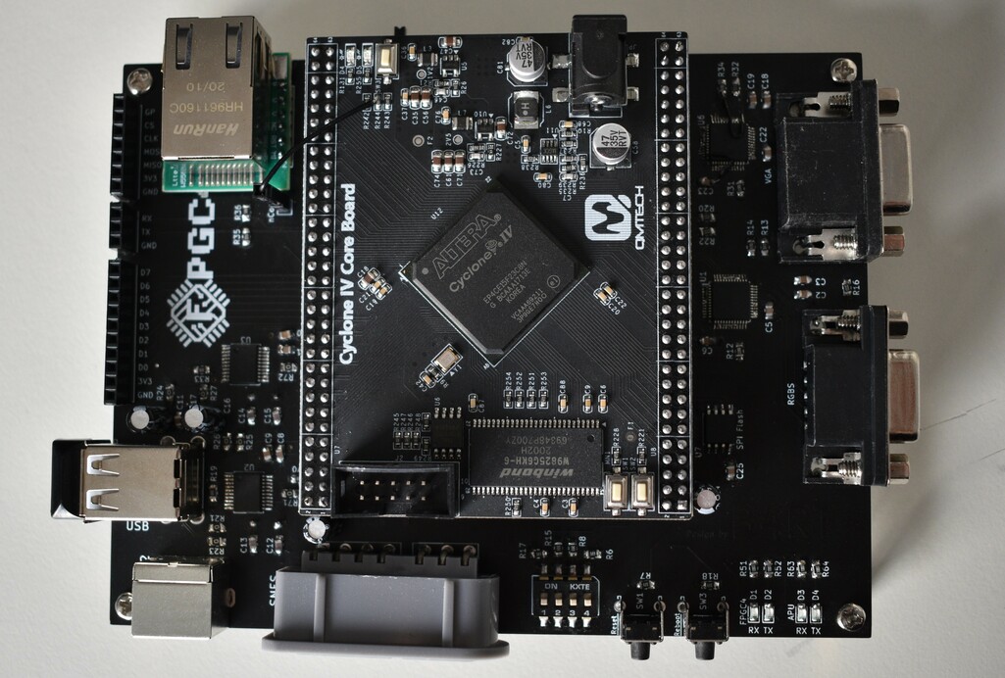
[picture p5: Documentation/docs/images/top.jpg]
top view


#### Front view

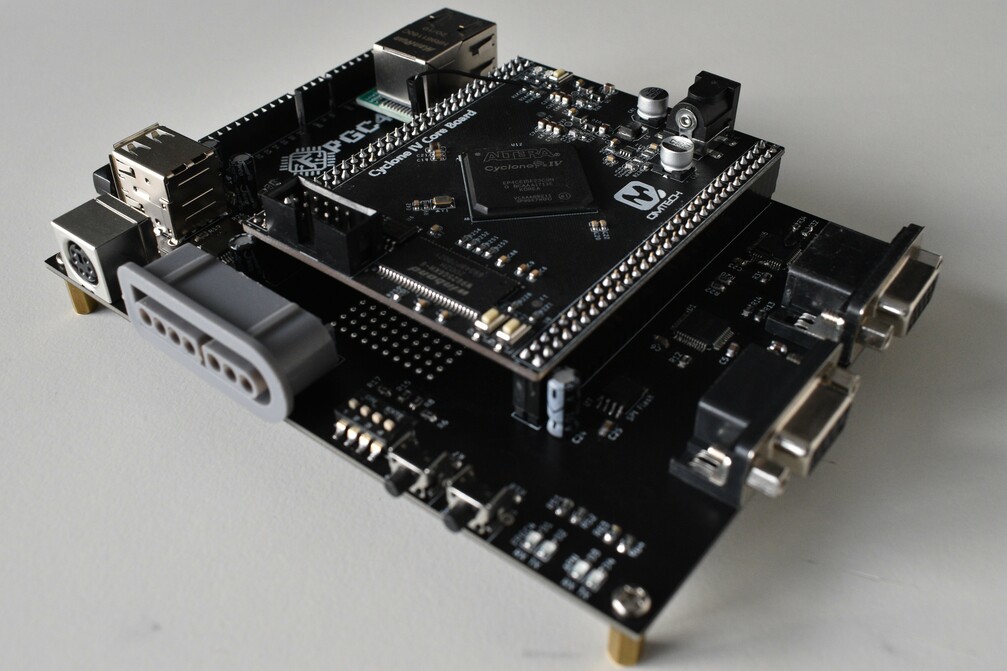
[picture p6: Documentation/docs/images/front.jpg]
front view


#### Rear view

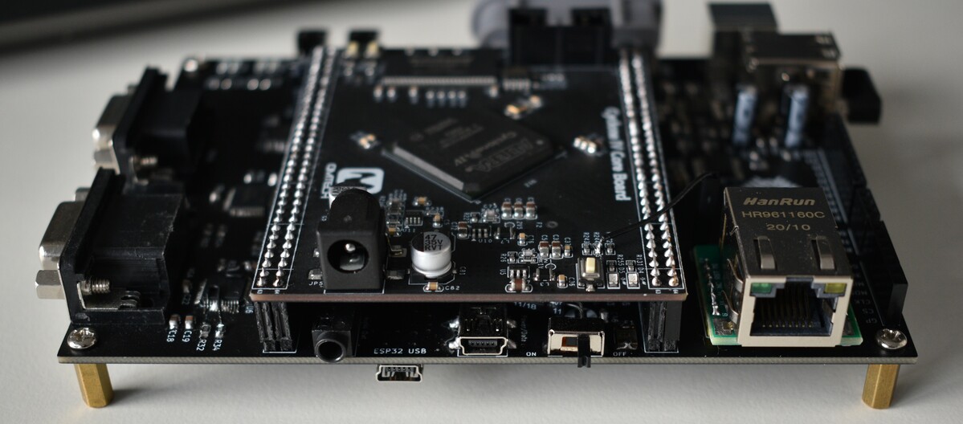
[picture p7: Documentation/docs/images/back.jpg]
rear view


#### Bottom view

There is a 'breadboard' on the bottom, with pins to the FPGA and power. You can also see the audio hardware of the FPGC5 (ESP32 with I2S DAC and FT232RL).

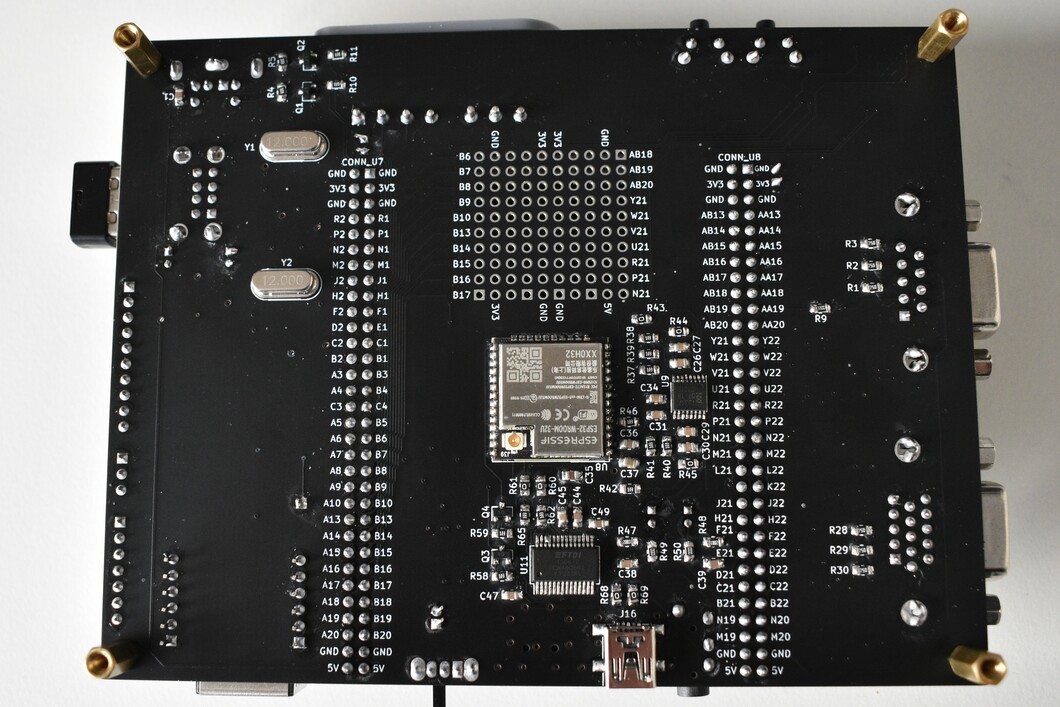
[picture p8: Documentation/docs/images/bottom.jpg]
bottom view


#### Core

The brain of the FPGC5: an EP4CE15 FPGA and 32MiB SDRAM.

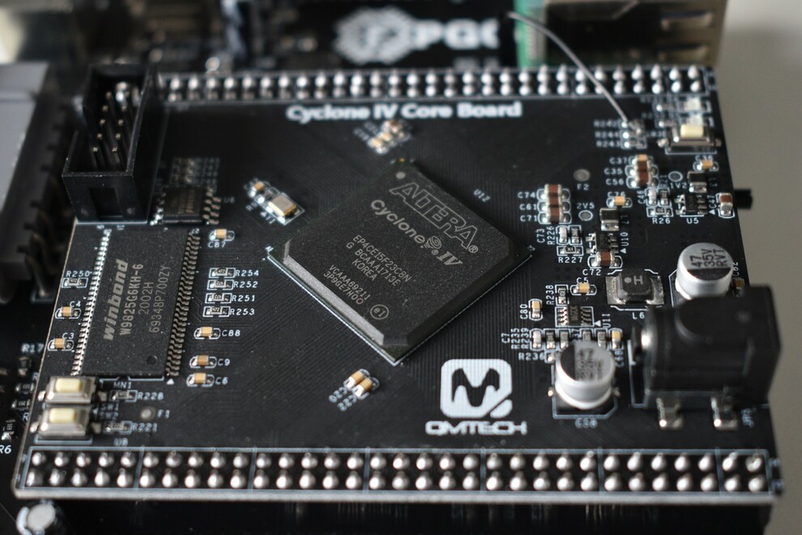
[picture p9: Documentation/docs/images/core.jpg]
core


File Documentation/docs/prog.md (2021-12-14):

# Programmer

!!! info "TODO"
	Very outdated :(

The Programmer folder contains all files related to programming the FPGC5 and the SPI flash. 

The compileROM.sh script converts the code.list file, the file with machine instructions in text, to a binary (code.bin) file. The file size will be a multiple of 4096 bytes, because the old external SPI flash programmer expects a file of this size. 

!!! info "TODO"
	Since the new SPI flash programmer does not have this restriction, this can be removed but should be tested first to make sure writing half a page does not break anything.

The final command in compileROM.sh sends the binary over UART to the FPGC5 using uartFlasher.py.

!!! info "TODO"
	Update the script to accept arguments, so you can choose to send it over UART (with a Windows verion option as well), program it to the SPI flash, or don't program it at all and write it to spi.txt for the Verilog simulator

## flash.py
To write a binary to the SPI flash, you can use the flash.py script. It uploads an SPI flasher binary to the FPGC5, which then accepts commands over UART and executes them to do operations on the SPI flash chip. This allows programming the SPI flash without the use of an external programmer. Currently it can erase, read and write the flash memory. When writing a binary and the verify argument is specified, the script will read the binary after writing to verify that the flash was successful (by comparing the two binary files using 'diff').

## uartFlasher.py
Since the second version of the I/O Board PCB, the SPI flash chip is not removable anymore. This means that using the UART interface remains the only way to send a program to the FPGC5. Therefore, I have added the UART bootloader code to the internal ROM of the FPGC5, which will be copied to SDRAM and executed when SPI boot is disabled.

The UART flasher script is used to send a binary file to the FPGC5 over UART (via the USB port) with a 115200 baud rate. When a Serial port is opened, the FPGC5 will reset allowing for fast programming without having to touch the board (assuming SPI boot is disabled).

All of this works by using some fancy tricks in the UART bootloader. The goal is to receive the bitstream from UART and copying it to SDRAM, starting from address 0, and jumping to address 0 after all bits are received. This gives the first problem: the bootloader should not overwrite itself, since it is also located and executed from SDRAM. All the copy instructions are placed around 16MiB. The first instruction is a HALT, which is placed at address 0 so the PC will always be at the first address. All the copy instructions are executed from the UART receive interrupt. When a byte is received, it is placed on SDRAM starting from 16MiB. This way the first HALT instruction remains the same. After all bytes are copied, a timer interrupt is used to copy the SDRAM from 16MiB to 0MiB. Then, when the interrupt has ended, the PC will start from the first instruction (where the HALT used to be), which should now be the first instruction of the sent code. See UARTSPIbootloader.asm for the code (warning: large file, because of the offset to 16MiB).

The uartFlasher_win.py version is a special version that should be executed from Windows (for use with WSL2).

After programming the FPGC5, a Serial monitor is opened where you can send text (by typing and pressing enter) and receive text from the FPGC5. Closing the Serial monitor (by pressing Ctrl-C) does NOT reset the FPGC5, only opening a Serial port does.

## netFlash.py
Using this script, you can currently send a binary file to the FPGC5 running BDOS. When successful, BDOS will execute the sent binary. In the future this script should become more of a network interface script with more functionality.

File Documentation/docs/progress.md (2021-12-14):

# Progress
Here I keep a list of my latest progress and a TODO list (very very outdated!)

## Big Progress log (truncated to latest progress, last entry at the bottom of the list)
- Reimplemented SPI module. Now uses 6.25MHz SPI clock (verified stable for CH376)
- Added a way to access SPI flash using a SPI(3) module. Can switch between SPIreader and SPI3 using a memory address
- Restructured Ccompiler changes to be less ad hoc and more streamlined (for working with and between memspots, regspots and literalspots)
- Designed and ordered V2 of the I/O Board PCB (4 layer)
- Created SPI flash programmer, removing the need for an external one
- Assembled new PCB
- New memory map, restructured the way SPI works (CS and Int), most libraries are updated now
- Started on OS (BDOS)
- Terminal GFX driver, FS driver, PS2 driver, USB keyboard driver, HID fifo driver done, started on shell
- More commands working for shell, new fast division algorithm
- USB bootloader (RUN command) and network bootloader implemented
- SPI speeds for flash and W5500 are now 25MHz

## TODO since new PCB
Things I need/want to fix/do since PCB v2 (has duplicates with Future plans)

- Implement true GPIO (Stabilize GPIO when module)
- Stabilize PS/2 input
- Add all signals to gtkwave for simulation
- Make pictures for documentation

## Future plans
These are kinda ordered based on priority

- Add option to compiler/assembler to compile for OS
- Write demo code in C, for OS
- Implement true GPIO
- Stabilize PS/2 input
- Stabilize GPIO when module
- Add all signals to gtkwave for simulation
- Improve C compiler
- Move ROM to MU
- Clean up and improve tools/scripts (arguments/functionality)
- Clean up unused files in PCB folders
- Change all static paths in the project to relative ones
- Improve ESP32Synth (for non-live settings, maybe midi buffer to reduce timers)
- Or, start designing Verilog Synth
- Improve sprite renderer design, since it uses (space/logic-wise) half of the entire design
- Create a pattern and palette table generator
- Write a platformer game
- Change speed of FT232RL to 1Mboud
- UART buffer mode in hardware
- Add Gameboy printer via Arduino to I/O

## Ideas
Random ideas that came up at some point. Some might be stupid tho.

- Create very very basic floating point unit, though it might be difficult to implement it into the C compiler
- Optimize timings in many Verilog files, since it has been quite some time
- Also, 'fix' as many warnings as possible
- Contstrain divided clocks?
- Write verilog tests for single modules

## Todo documentation
- BDOS page
	- memory map
	- all functions/libraries
- table of interrupt ids and how to obtain them
- gallery page
- installation/setup page
- build it yourself page
- really, I should add more pictures and examples (of video output, simulation, hardware)
- add DSUB9 pinout
- add (probably in specs section) the FPGA usage statistics
	- note that the sprite renderer takes almost half of the FPGA, because many big registers
- talk about memory bottleneck, Instructions per clock cycle
- add design mistakes for io wing (uart pulldown, no shield to ground)
- add uart bootloader code/description to bootloader section
- think about removing bootloader code in documentation
- add some snippet of code + binary in assembler documentation
- check if uart bootloader jumpt to addr 5 or addr 0 when done
- add something about the nconf button remapping wire on the PCB page
- add something about the automatic dtr reset
- add new functions to assembler page
	- rbp rsp mapped to r14 r15 for c compiler
	- added negative offset option for read, write and copy instruction
- add picture of SPI flasher, and add/improve instructions on how to use them (seperate page + commands + hardware mod of spi module)
- add something about WSL2
- note that r7 is used as temp reg to store address of label in read/write instructions
- only global int and int[x] are allowed, no char, since size allocation goes wrong
- register/assembly info for c compiler
- add schematic of pcb
- add info about w5500 hardware and software
- note about how to get the USB flash drive to properly formatted: Minitool Partition Wizard, reinitialize MBR, add Fat32 value with cluster? size of 2KB

## Todo C compiler related
- [done] Add neg offset flag in READ and WRITE and COPY instructions
- [done] Implement neg offset for READ and WRITE and COPY instructions
- [done] Map the name rbp and rsp to r14 and r15 in assembler
- [done] add int1-4 functions, with automatic backup and restore of ALL registers to HW stack
- [done] add prefix main (as header) with load 0x700000 rsp
- [done] in asm main prefix header, get return value from label_main and send it over UART
- [done] add more instructions and test files
- [done] add inline assembly for fast code like copying tables
- [done] add static defines
- [done] add hex support!!! (and binary while at it) (also in defines)
- [done] add bitwise | ^ and & operators (look at commit 31180511de0f95cf5dbda0bf98df71901a2fd1ed)
- [done] print static string in correct asm format (.dw without commas)
- [done] Fix empty label problem in ASSEMBLER! by adding a nop when detected
- [done] Rewrite and streamline il_cmds
- Fix global array indexing using variables in global variables
- Improve global array definition (eg: when no value is set)
- Fix commenting out asm code
- Remove requirement to add intX() functions
- Add wrapper for extended interrupts
- Improve performance of certain libraries by using assembly
- Add timer 1 interrupt code to assembly wrapper
- Change or r0 const rx to load const rx
- Maybe add some hotfix for number not fitting in register by using temp reg
- eventually clean up code, remove size arg

## Future hardware/pcb improvements
- Stop using hard to solder 32bit video dacs, and go back to a simple but 75ohm terminated 8 bit resistor dac (Which will fix yellow-ish white as well, use op-amps or buffers)
- Make sure logo is not covered up by W5500 module
- Pull-down? on dtr
- Find out what draws so much current
- New audio solution (TODO: requirements and goals)

## Future improvements (FPGC5?)
- Do not use any negedge statements. Do everything on posedge, because everyone says that is the way to go when using FPGAs
- Separate set of registers for interrupts, or an instruction that backs up/swaps given registers (bit per register)
- Better bus protocol between CPU and MU, with no cycles overhead
- Byte addressable memory
- Maybe DMA controller (probably not tho, unless useful for future OS)
- Maybe some way to use 3D rendering with a frame buffer, though it is already complicated to make use of 2D rendering.
- Optimize SPI to SDRAM by using one (two including size) big sequential read

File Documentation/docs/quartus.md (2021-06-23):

# Quartus

!!! info "TODO"
	Add picture of usage

The Quartus folder contains all files for actually implementing the FPGC5 into hardware on an FPGA. The targeted development board is the QMTECH EP4CE15 core board with 32MiB SDRAM.

There are some slight changes between the code in the Verilog folder and the code in the Quartus folder. For example, the Verilog folder contains simulation files for the SPI flash and SDRAM memory. The Quartus project is on the top level slightly modified to work on an actual FPGA. This also includes the use of PLLs for creating clocks.

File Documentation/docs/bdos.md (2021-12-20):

# BDOS

!!! danger
    Since I am adding so many new features, this info will be very outdated

BDOS (or Bart's Drive Operating System) is a single-tasking operating system for the FPGC written in C and assembly. Its goal is to provide a user interface (shell) to load programs from storage an to do other basic drive operations. These programs still have full access to all hardware as if it is running on bare metal. The only difference is that the program is ran from `0x400000` instead of `0x000000` and that interrupts first go through BDOS before reaching the program. Therefore, some compiler changes will need to be made for running programs on BDOS. Furthermore, BDOS user programs have access to the OS via system calls. These system calls can be used, for example, to get HID inputs from the HID FIFO, or to print characters to the shell. While technically not required, they do make the programs a lot simpler.

While this is definitely not a complex OS like Linux or Windows, it does add a lot of functionality to the FPGC. Mainly the shell and the ability to load programs from USB and Network are a huge step-up over the MCU-like programming experience where you can only run one program until it is reprogrammed.

!!! danger
    Timer2 is used for USB keyboard polling, so don't use it in user code!

## Functionality
Currently, with BDOS you can:
- Navigate and do other operations on the file system on a USB drive using the shell
- Run programs from the file system
- Run programs sent over the network
- Use a PS/2 keyboard and/or USB keyboard to interface with shell
- Use system calls in your user programs
- Return to BDOS after a user program terminates (sucessfully)

### Future ideas
Features that I might want to implement in the future:
- History of commands (in file?), so I can use the arrow keys
- Path of executables that can be directly executed without RUN command
- Download a sent file from the network to the USB drive, using the headers of the network frame (!)

## Memory Map
BDOS has its own layout of the 32MiB SDRAM, which you can see here. There really is no need for such big chunks of memory, but I have no other purpose for it for now.

Note: addresses are 32 bit, so 0x100000 is 4MiB

``` text
SDRAM
$000000 +------------------------+
        |                        |
        |                        |
        |         (8MiB)         |
        |   BDOS Program Code    |
        |                        |
        |                        |
        |                        | $1FFFFF
$200000 +------------------------+
        |        (256KiB)        |
        | Syscall Arg + Retval   | $20FFFF
$210000 +------------------------+
        |       (7.75MiB)        |
        |   TMP Output Buffer    |
        |           &            |
        | Syscall Stack (at end) | $3FFFFF
$400000 +------------------------+
        |         (13MiB)        |
        |   User Program Memory  |
        |           &            |
        |User Main Stack (at end)|
        |                        | $73FFFF
$740000 +------------------------+
        |         (1MiB)         |
        |BDOS Main Stack (at end)|
        |                        | $77FFFF
$780000 +------------------------+
        |         (1MiB)         |
        | User Int Stack (at end)|
        |                        | $7BFFFF
$7C0000 +------------------------+
        |         (1MiB)         |
        | BDOS Int Stack (at end)|
        |                        | $7FFFFF
        +------------------------+

```

## BDOS OS Libraries
BDOS has it own set of libraries and data, which you can see in the `Ccompiler/BDOS/` folder. These are not accessable to user programs. Those have their own set of libraries.

### gfx.h
The graphics library provides, on top of the basic functions from the general C library, functionality to write characters to screen as if it was a console. This means that the screen scrolls vertically when the last line is written. A cursor is also kept in memory. Newlines and backspaces are also supported.

### ps2.h
The PS2 keyboard library provides an interrupt handler for extracting keypresses from scancodes. It can handle shifted keys and extended keys. See ps2.h for more details on what is supported and what is not.

### usbkeyboard.h
A library for reading keypresses from an USB keyboard. AFAIK it currently only works for some USB2.0 keyboards. The top USB port is used for this. The keyboard is polled using a timer (timer2, so don't use it in user code).

### hidfifo.h
A FIFO for storing keypresses from PS/2, USB keyboard and SNES controller. The shell can read these key presses without needing to know from which device.

### stdlib.h
Provides basic functions and the blocking delay() function using timer1.

### math.h
Provides very very basic math operations which are not efficiently implemented at all.

### fs.h
Provides functionality for operating the filesystem on a flash drive in the bottom usb port.

### wiz5500.h
Provides functionality for operating the Wiznet W5500 chip. Supports eight sockets.

### netloader.h
A network based bootloader using the wiz5500.h library.

### shell.h
Provides the implementation of the shell for operating the system.

## BDOS user program libraries
User programs have their own set of libraries and data, which you can see in the `Ccompiler/userBDOS/` folder. While mostly similar to the BDOS libraries, some libraries like HID related drivers and the shell are removed or different, since those are only useful for the OS or should be called using system calls. Most importantly, there is a library `sys.h` that allows for system calls to BDOS.

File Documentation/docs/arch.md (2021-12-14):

# Architecture
The FPGC consists of four main parts: the CPU, GPU, MU and APU, where the APU still has to be implemented

The CPU, called the B322, is the main part that executes all instructions. It reads and writes to the MU. The CPU consists of an timer that handles the timing of the CPU phases, an instruction decoder that splits the 32 bits of each instructions, an PC unit that handles all program counter related functions like jumps and interrupts, an ALU that can do 16 different operations on two 32 bit inputs, a register bank that contains 16 32 bit registers, a stack and finally a control unit that directs certain signals based on the instruction.
 
The GPU, called the FSX2, is completely separate from the CPU. It contains the logic for generating a video signal and for creating an image on this signal based on the contents of VRAM. The GPU has its own read port with clock on the VRAM, since all of it is true dual port SRAM, allowing it to run on a completely different clock domain than the rest of the FPGC.

The MU, or memory unit, handles all memory access between the CPU and all the different memories used in the FPGC. These memories includes: SDRAM, SPI flash, internal ROM, 8 bit VRAM, 9 bit VRAM, 32 bit VRAM and a lot of I/O like UART and SPI ports and a PS/2 keyboard register. The MU makes use of a memory map to allow the CPU to access these memories. The goal of the MU is to have the CPU access all memories without the CPU having to care about the type or timing of the memory, making an easy memory interface for the CPU. This is achieved using a bus protocol. However, this does cost one cycle of overhead per operation on the MU in most cases.

The APU, or audio processing unit, still has to be implemented, and will be using an I2S DAC to generate the analog audio.

Block diagram of FPGC:

``` text
                  +---------------------+
                  |                     |
                  |        B322         |
                  |         CPU         |
                  |                     |
                  |                     |
                  +---------------------+
                             ^
                             |
                             v
+---------+       +---------------------+       +---------+       +---------+
|         |       |                     |       |         |       |         |
|  SDRAM  |<----->|                     |       |         |       |         |
|         |       |                     |       |         |       |         |
+---------+       |                     |       |         |       |  FSX2   |
                  |       Memory        |<----->|  VRAM   |<----->|   GPU   |
+---------+       |        Unit         |       |         |       |         |
|         |       |                     |       |         |       |         |
|   ROM   |<----->|                     |       |         |       |         |
|         |       |                     |       |         |       |         |
+---------+       +---------------------+       +---------+       +---------+
                        ^          ^
                        |          |
                        v          v
                    +-------+  +-------+
                    |       |  |       |
                    |  SPI  |  |  I/O  |
                    | flash |  |       |
                    |       |  +-------+
                    +-------+ 
```

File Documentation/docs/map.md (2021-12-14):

# Memory map
The FPGC5 uses two memory maps to access all different types of memory and I/O.
One map is used by the CPU (and implemented by the MU) and the other map is used by the GPU. The GPU memory map is only useful when developing the GPU (in Verilog), so for writing code, you only need to understand the CPU memory map.

## CPU memory map
When the CPU gets a `READ`, `WRITE` or `COPY` instruction, it will use the following memory map. This means that, for example, reading from address `0xC02622` will read the button states of the (S)NES controller, and writing to address `0xC0041F` will write an entry in the Palette Table for the GPU.
Note: the memory map has been rearranged since the second version of the I/O Board. This means that older code that has not been updated will not work anymore.

``` text
$000000 +------------------------+ 
        |                        | 
        |         SDRAM          | 
        |                        | $7FFFFF 
$800000 +------------------------+ 
        |                        | 
        |       SPI FLASH        | 
        |                        | $BFFFFF 
$C00000 +------------------------+ 
        |                        | 
        |         VRAM32         | 
        |                        | 
        | $C00000                | 
        |     Pattern Table      | 
        |                $C003FF | 
        |                        | 
        | $C04000                | 
        |     Palette Table      | 
        |                $C0041F | 
        |                        | $C0041F 
$C00420 +------------------------+ 
        |                        | 
        |         VRAM8          | 
        |                        | 
        | $C00420                | 
        |    BG Pattern Table    | 
        |                $C00C1F | 
        |                        | 
        | $C00C20                | 
        |    BG Palette Table    | 
        |                $C0141F | 
        |                        |
        | $C01420                | 
        |  Window Pattern Table  | 
        |                $C01C1F | 
        |                        | 
        | $C01C20                | 
        |  Window Palette Table  | 
        |                $C0241F | 
        | $C02420                | 
        |       Parameters       | 
        |                $C02421 |  
        |                        | $C02421 
$C02422 +------------------------+ 
        |                        |
        |       SpriteVRAM       |
        |                        | $C02521 
$C02522 +------------------------+ 
        |                        | 
        |          ROM           |
        |                        | $C02721
$C02722 +------------------------+ 
        |                        | 
        |          I/O           | 
        |                        |
        | UART0 RX (MAIN)$C02722 |
        | UART0 TX (MAIN)$C02723 |
        | Unused         $C02724 |
        | Unused         $C02725 |
        | UART2 RX (EXT) $C02726 |
        | UART2 TX (EXT) $C02727 |
        | SPI0   (FLASH) $C02728 |
        | SPI0_CS        $C02729 |
        | SPI0_ENABLE    $C0272A |
        | SPI1 (CH376_0) $C0272B |
        | SPI1_CS        $C0272C |
        | SPI1_nINT      $C0272D |
        | SPI2 (CH376_1) $C0272E |
        | SPI2_CS        $C0272F |
        | SPI2_nINT      $C02730 |
        | SPI3   (W5500) $C02731 |
        | SPI3_CS        $C02732 |
        | SPI3_INT       $C02733 |
        | SPI4     (EXT) $C02734 |
        | SPI4_CS        $C02735 |
        | SPI4_GP        $C02736 |
        | GPIO           $C02737 |
        | GPIO_DIR       $C02738 |
        | Timer1_val     $C02739 |
        | Timer1_ctrl    $C0273A |
        | Timer2_val     $C0273B |
        | Timer2_ctrl    $C0273C |
        | Timer3_val     $C0273D |
        | Timer3_ctrl    $C0273E |
        | Unused         $C0273F |
        | PS/2 Keyboard  $C02740 |
        | BOOT_MODE      $C02741 |
        +------------------------+ $C02741

```

## GPU memory map
This memory map is only used in the GPU. These are basically the content read from the GPU port of VRAM. This map is only internal to the GPU hardware, and should/can not be used when writing code (use the CPU memory map instead for this!). This map is only useful when making modifications to the GPU in Verilog.
``` text
VRAM32
$000  +------------------------+ 
      |                        | 
      |     Pattern Table      | 
      |                        | $3FF
$400  +------------------------+ 
      |                        |
      |     Palette Table      |
      |                        | $41F
      +------------------------+

VRAM8
$000  +------------------------+
      |                        | 
      |     BG Tile Table      | 
      |                        | $7FF
$800  +------------------------+ 
      |                        |
      |     BG Color Table     |
      |                        | $FFF
$1000 +------------------------+
      |                        | 
      |   Window Tile Table    | 
      |                        | $17FF
$1800 +------------------------+ 
      |                        |
      |   Window Color Table   |
      |                        | $1FFF
$2000 +------------------------+
      |                        |
      |       Parameters       |
      |                        | $2001
      +------------------------+

SpriteVRAM
$000  +------------------------+
      |                        | 
      |    %0: X pos           | 
      |    %1: Y pos           | 
      |    %2: Tile            | 
      |    %3: Palette+flags   | 
      |                        | $FF
      +------------------------+ 
```

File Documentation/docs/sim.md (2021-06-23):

# Simulation

!!! info "TODO"
	Write this out

- using Icarus Verilog and GTKwave
- instructions how to simulate
	- add things you want to test in \*\_tb.v
	- testbench dumps all signals to a .wave file for GTKwave
	- run the testbench with 
		iverilog -o output FPGC_tb.v && vvp output
		(you can use the verilog build script in the SublimeText3 folder if you use Sublime Text 3)
- screenshot of simulation

<figure>
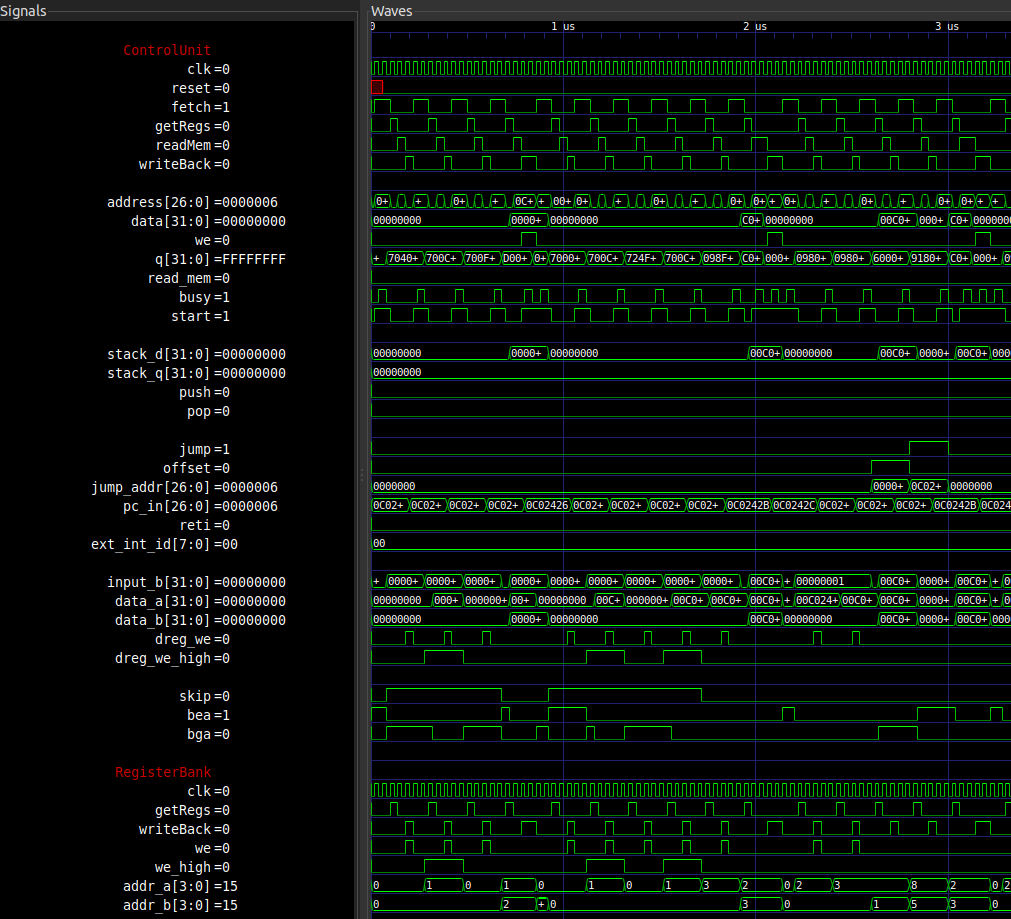
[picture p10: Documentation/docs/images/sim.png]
Memory Unit waveform
    
    <figcaption>Example screenshot of simulation in GTKwave</figcaption>
</figure>

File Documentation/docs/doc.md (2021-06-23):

# Documentation

!!! info "TODO"
	Remove this page eventually

- you need mkdocs (pip3 install mkdocs)
- also you need mkdocs-material from pip3
- to work on the documentation:
	- execute ./run.sh to host a local version on localhost:6969
	- when a file is changed, the website should refresh automatically
- to deploy the website on the server (notes for self):
	- execute ./deploy.sh
	- this will:
		- build the site to the ./site directory
		- remove the old fpgc4 folder on the server
		- copy the site directory to the server, with fpgc4 as name
		- recursively set group to www-data
	- just make sure you use public key authentication to the server

## Notes for markdown documentation

!!! note ""
    Note example

!!! info 
	yeet

!!! info "TODO"
	todo

!!! tip
    hot

!!! success
    Lorem

!!! question
    whomst'd've?

!!! fail
    f

!!! danger
    risk

!!! bug
    to fix

!!! example
    ```
    code
    ```

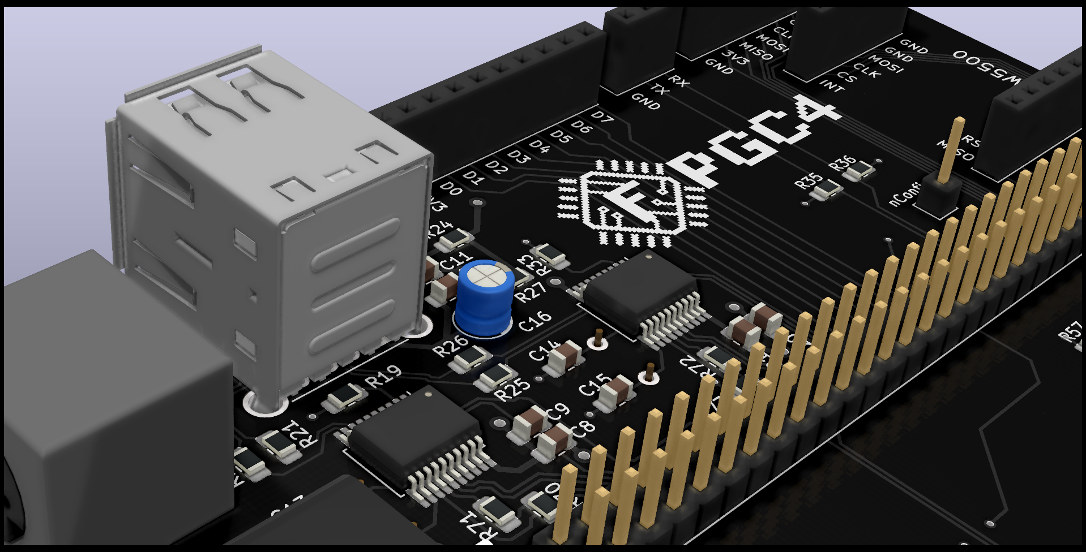
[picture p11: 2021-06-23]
PCB/FPGC5IOboard/renders/FPGC4IOboardV2TopCloseUp.png

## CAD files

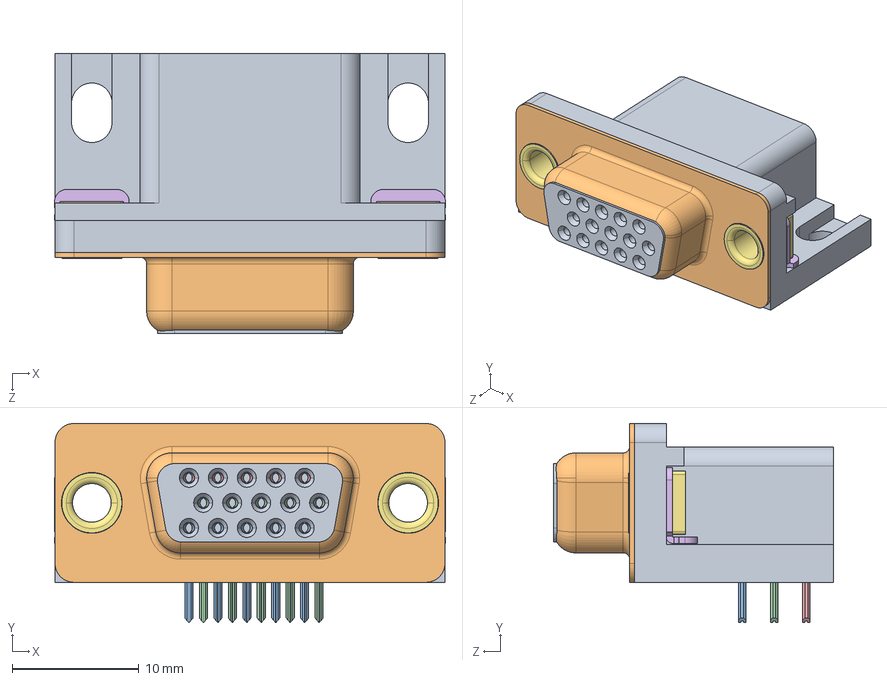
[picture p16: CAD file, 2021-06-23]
PCB/FPGC5IOboard/conn_d-sub/edac.STEP
30.9 x 15.7 x 22.1 mm
634 Housing
634 Shell
Contact Bottom x 5
Contact Middle x 5
Contact Top x 5
Non Board Mount x 2
Thru Hole Rivet x 2

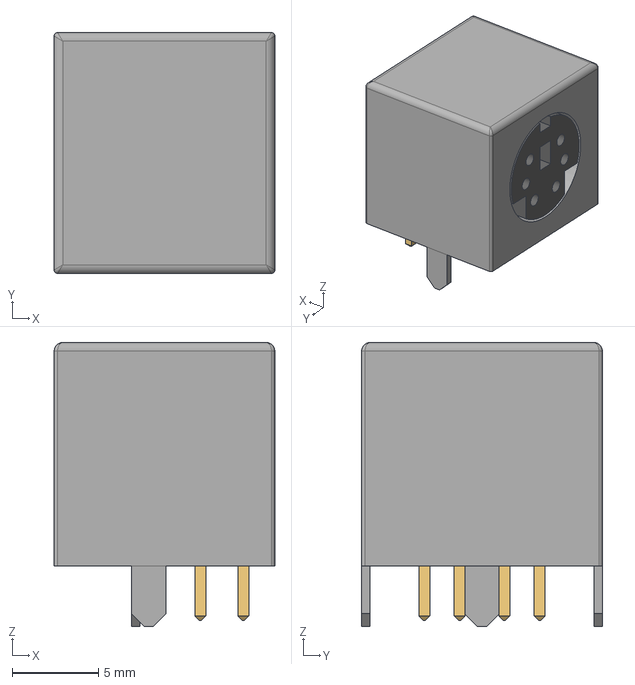
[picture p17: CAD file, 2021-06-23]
PCB/FPGC5IOboard/mini-din-6p-1.snapshot.2/Mini-DIN-6P.step
12.8 x 14.0 x 16.5 mm

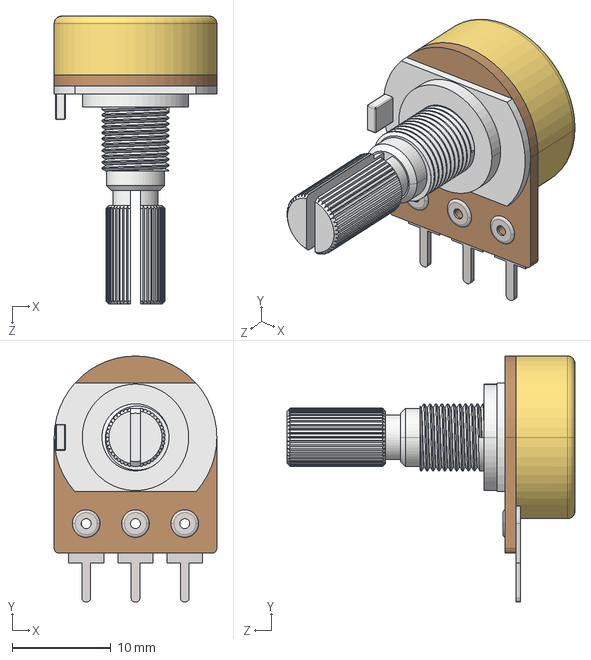
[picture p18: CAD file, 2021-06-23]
PCB/FPGC5IOboard/pot3D/pot.step
16.5 x 24.9 x 29.2 mm

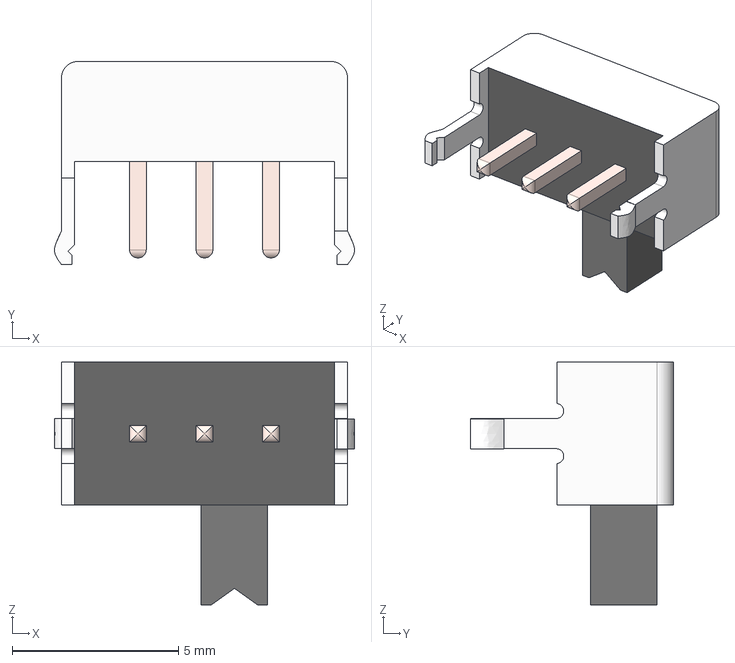
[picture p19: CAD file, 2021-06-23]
PCB/FPGC5IOboard/switch3D/switch.step
9.01 x 6.10 x 7.30 mm

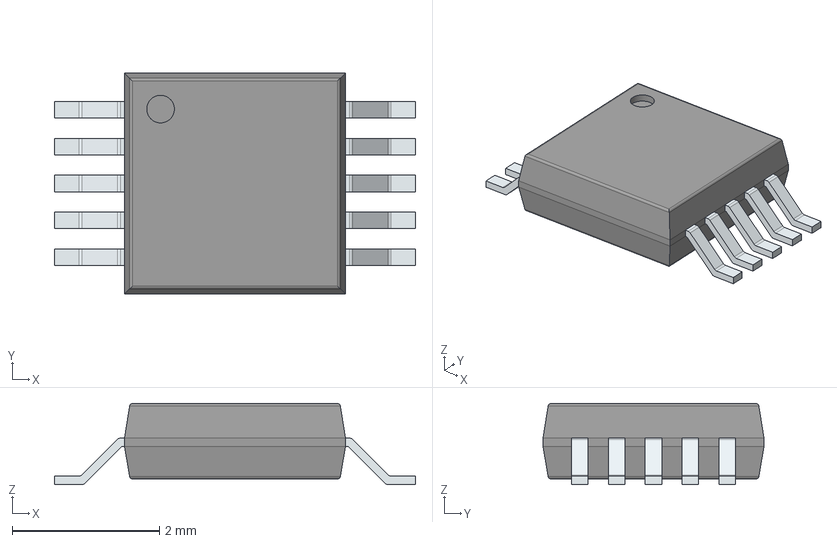
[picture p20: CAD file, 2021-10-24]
PCB/KicadSteps/CS4344-CZZ.stp
4.90 x 3.00 x 1.10 mm
PinsArrayLR

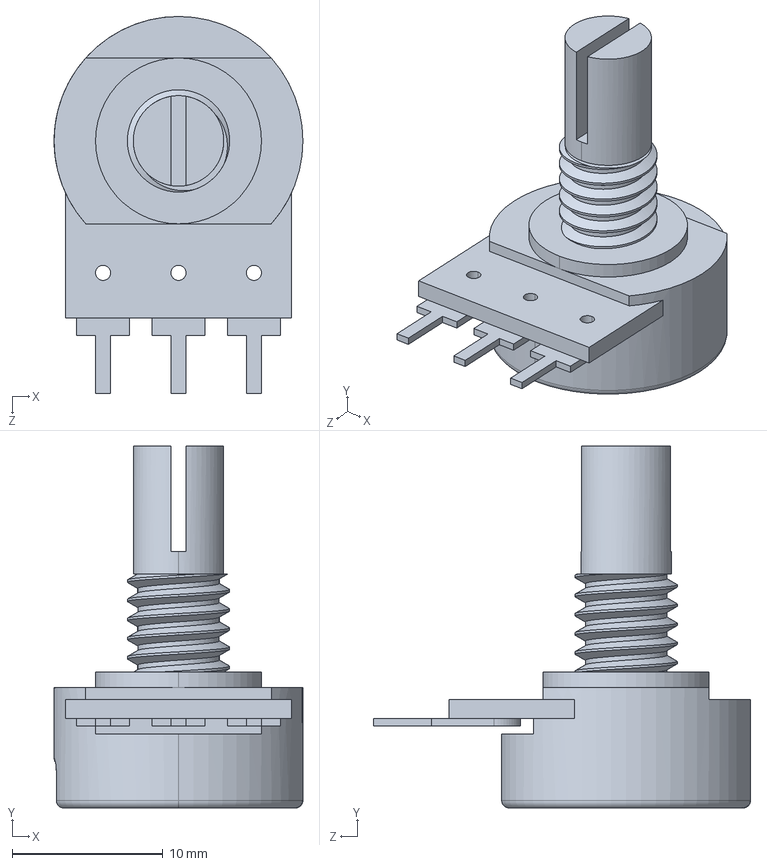
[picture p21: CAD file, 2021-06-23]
PCB/FPGC5IOboard/pot3D/potentiometer.step
16.5 x 24.0 x 25.0 mm

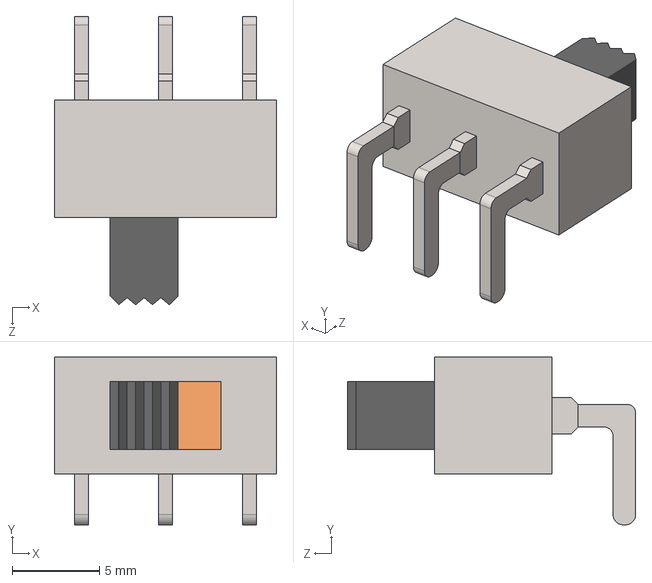
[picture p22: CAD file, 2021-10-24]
PCB/KicadSteps/SS12D06-1.step
12.7 x 9.60 x 16.5 mm

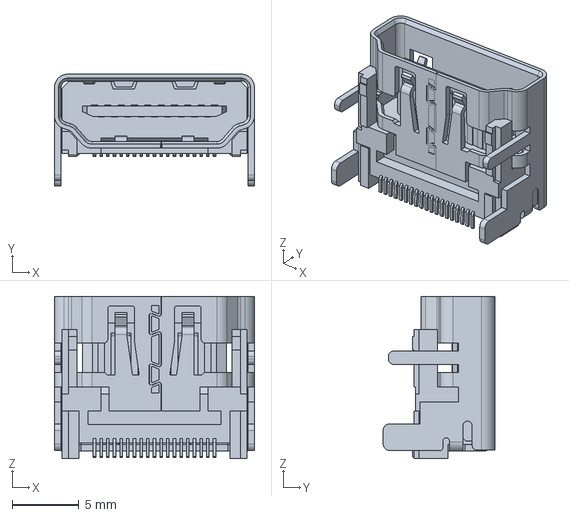
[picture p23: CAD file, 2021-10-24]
PCB/KicadSteps/HDMI.stp
15.0 x 8.38 x 12.2 mm

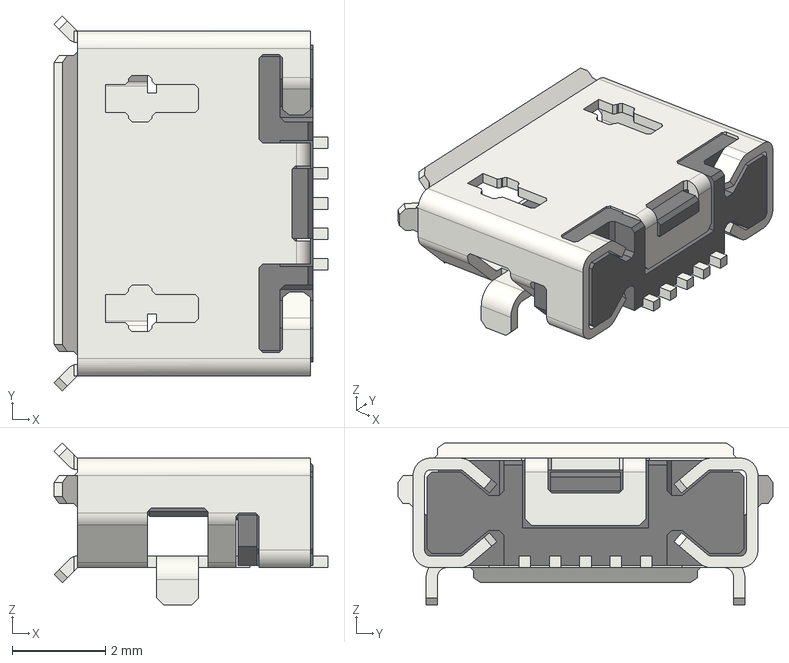
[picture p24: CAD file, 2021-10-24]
PCB/KicadSteps/Conn_USB-micro-2.0_socket_right-angle.step
5.88 x 8.05 x 3.47 mm

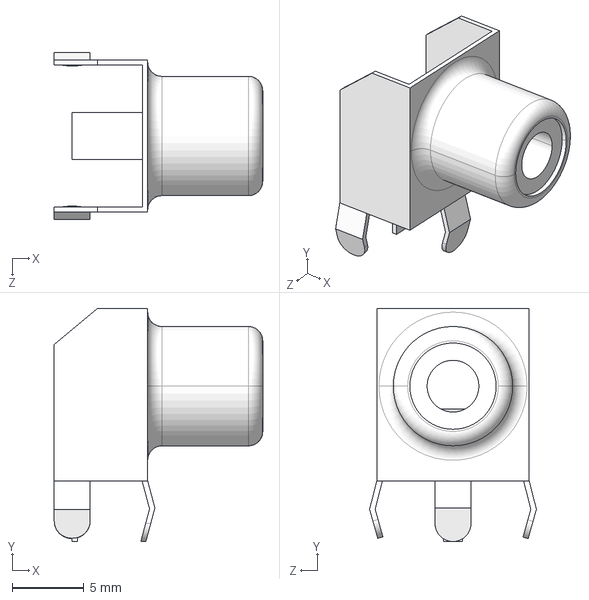
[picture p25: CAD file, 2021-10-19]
PCB/KicadSteps/CUI_DEVICES_RCJ-013.step
14.5 x 16.2 x 11.6 mm

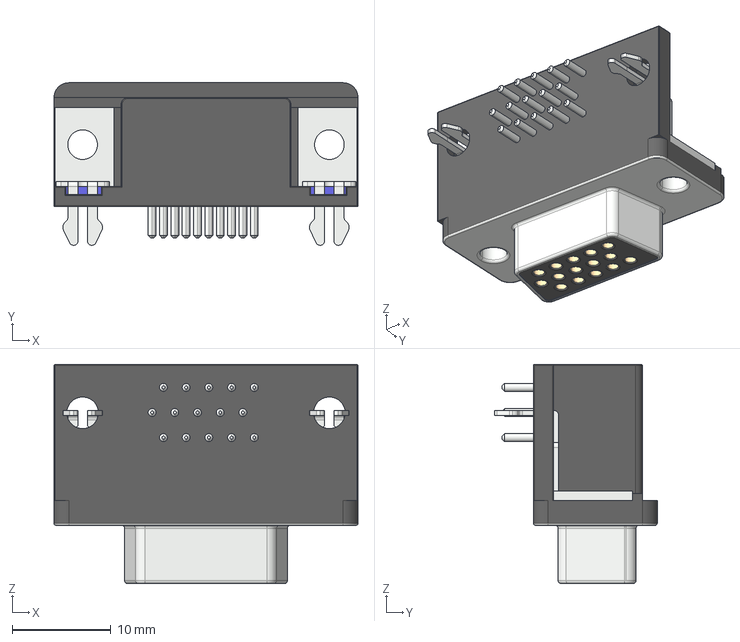
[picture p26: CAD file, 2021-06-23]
PCB/KicadSteps/VGAblack.step
30.8 x 16.5 x 22.2 mm

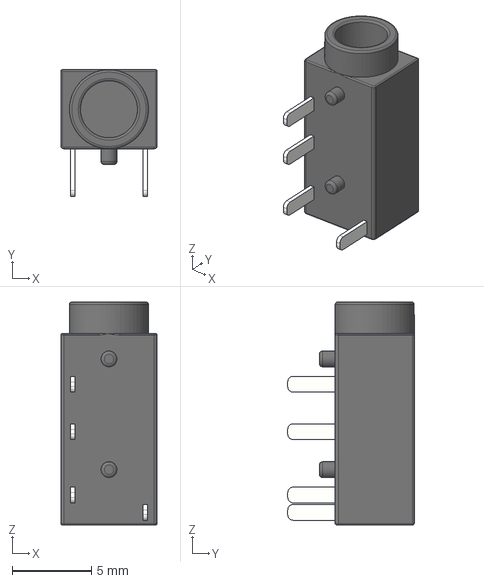
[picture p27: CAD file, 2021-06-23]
PCB/KicadSteps/PJ-320A.step
6.10 x 8.00 x 14.1 mm

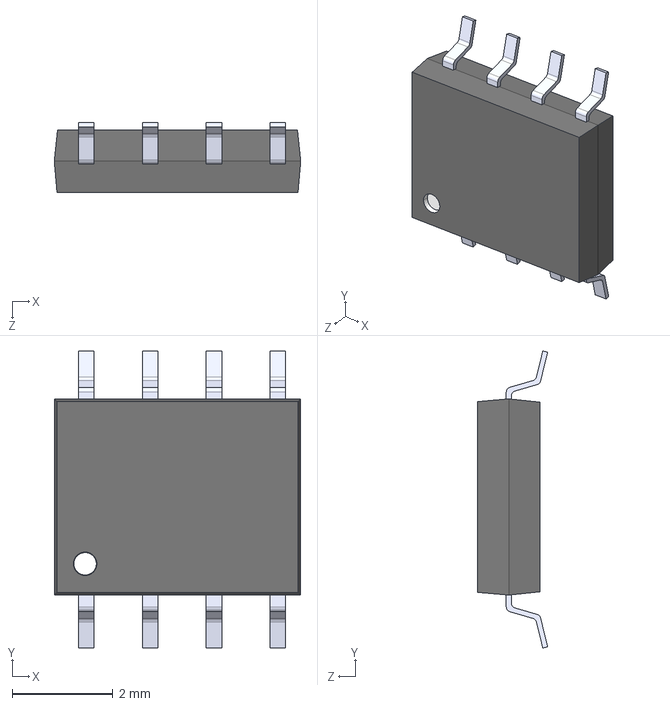
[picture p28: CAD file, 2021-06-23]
PCB/KicadSteps/soic8.STEP
4.90 x 5.90 x 1.40 mm

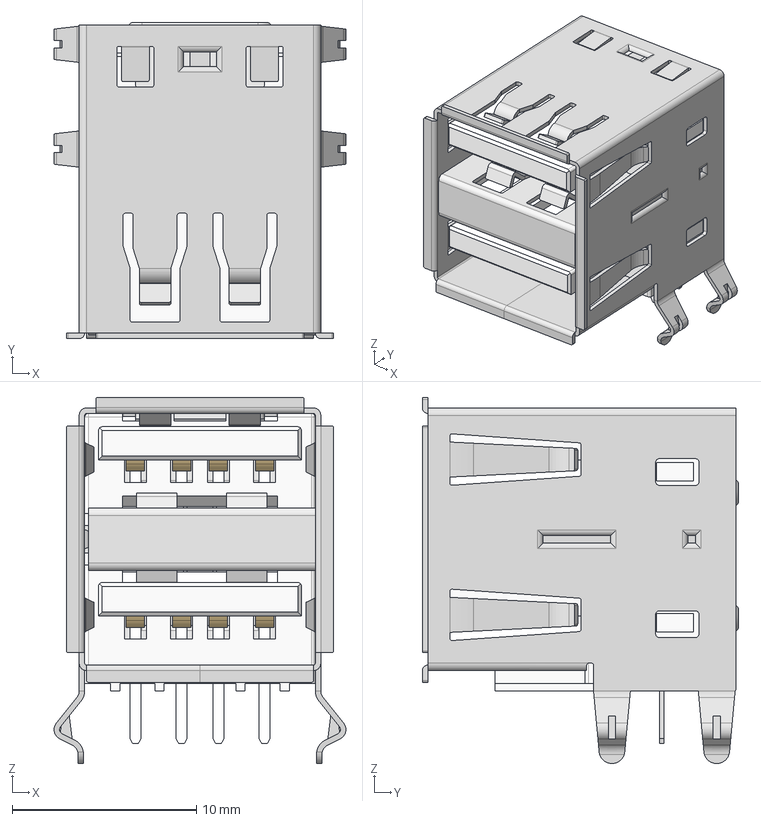
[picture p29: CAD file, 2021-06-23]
PCB/KicadSteps/USBstack.stp
15.8 x 17.1 x 19.8 mm
61400826021_Shielding1
61400826021_Housing
61400826021_Shielding2
61400826021_Pin2 x 4
61400826021_Pin1 x 4
61400826021_Shielding3

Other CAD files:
PCB/KicadSteps/VGA.STEP
PCB/FPGC5IOboard/3.5mm3D/FC68128.step
PCB/FPGC5IOboard/mini-din-6p-1.snapshot.2/Mini-DIN-6P.fcstd
PCB/FPGC5IOboard/mini-din-6p-1.snapshot.2/Mini-DIN-6P.iges

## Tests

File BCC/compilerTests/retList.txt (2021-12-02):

a   7
b   0
c   12
d   8
e   8
f   15
g   2
h   15
i   11
j   99
k   97
l   61
m   7
n   124
o   30
p   120
q   106
r   10
s   15
t   18
u   7
v   6
w   99
x   117
y   7

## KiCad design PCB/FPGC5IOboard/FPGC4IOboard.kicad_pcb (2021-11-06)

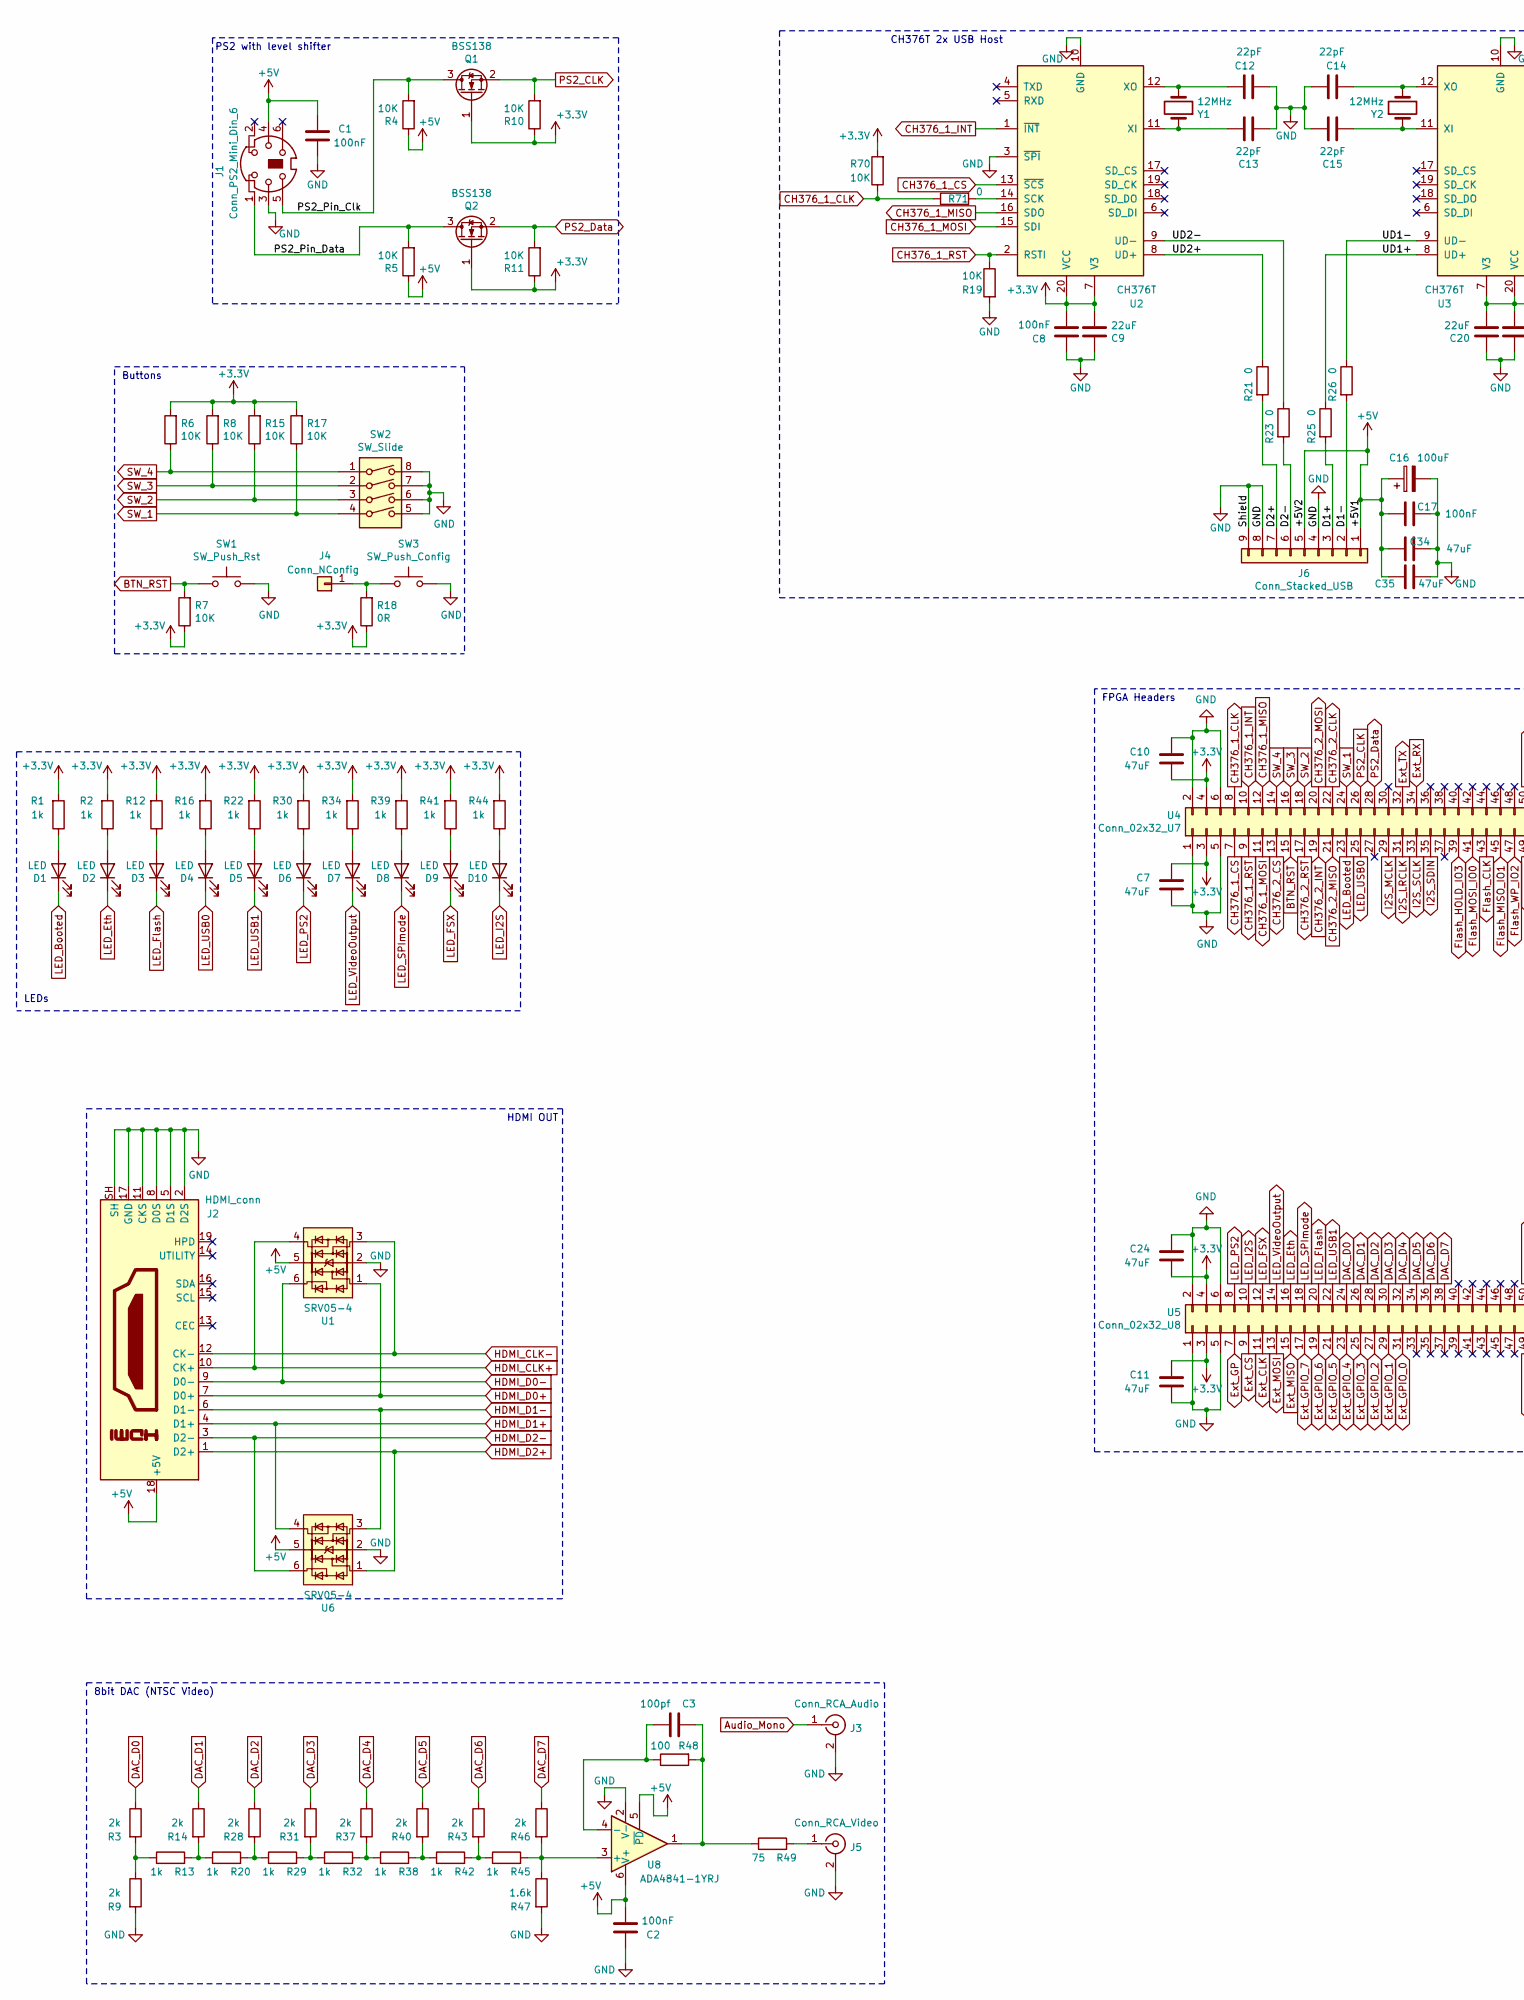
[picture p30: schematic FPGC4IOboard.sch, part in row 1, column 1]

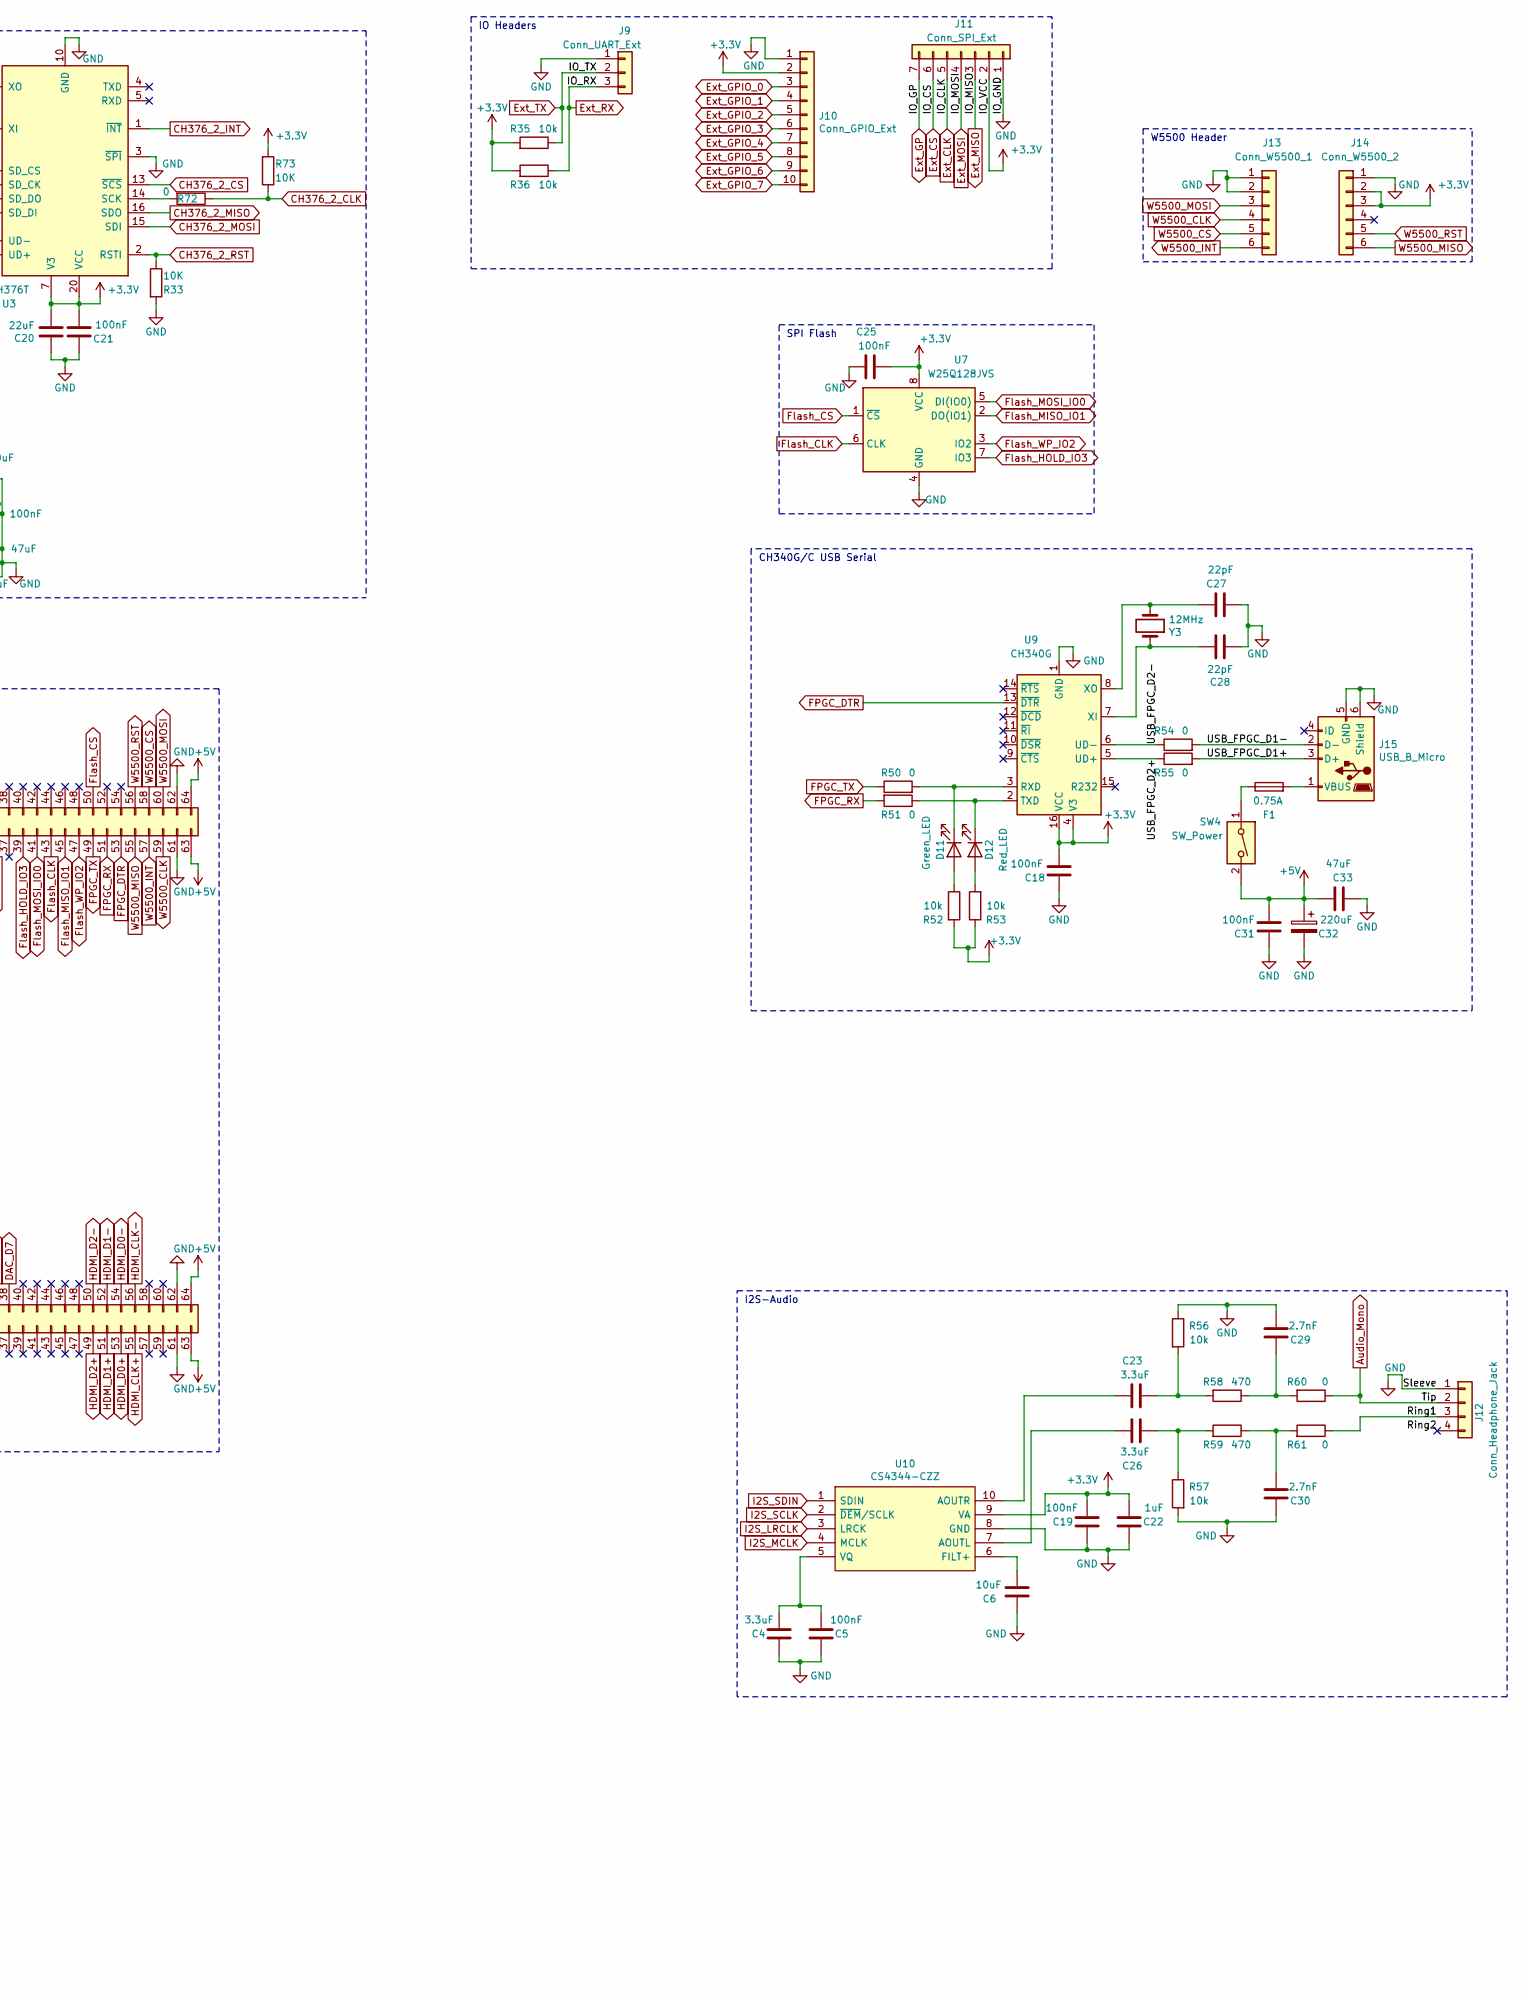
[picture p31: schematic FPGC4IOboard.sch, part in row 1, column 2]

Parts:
C1, C2, C5, C8, C17, C18, C19, C21, C25, C31: 100nF; C_0805_2012Metric_Pad1.18x1.45mm_HandSolder
C3: 100pf; C_0805_2012Metric_Pad1.18x1.45mm_HandSolder
C4, C23, C26: 3.3uF; C_0805_2012Metric_Pad1.18x1.45mm_HandSolder
C6: 10uF; C_0805_2012Metric_Pad1.18x1.45mm_HandSolder
C7, C10, C11, C24, C33, C34, C35: 47uF; C_0805_2012Metric_Pad1.18x1.45mm_HandSolder
C9, C20: 22uF; C_0805_2012Metric_Pad1.18x1.45mm_HandSolder
C12, C13, C14, C15, C27, C28: 22pF; C_0805_2012Metric_Pad1.18x1.45mm_HandSolder
C16: 100uF; CP_Radial_D4.0mm_P2.00mm
C22: 1uF; C_0805_2012Metric_Pad1.18x1.45mm_HandSolder
C29, C30: 2.7nF; C_0805_2012Metric_Pad1.18x1.45mm_HandSolder
C32: 220uF; CP_Radial_D5.0mm_P2.00mm
D1, D2, D3, D4, D5, D6, D7, D8, D9, D10: LED; LED_0805_2012Metric_Pad1.15x1.40mm_HandSolder
D11: Green_LED; LED_0805_2012Metric_Pad1.15x1.40mm_HandSolder
D12: Red_LED; LED_0805_2012Metric_Pad1.15x1.40mm_HandSolder
F1: 0.75A; Fuse_1812
J1: Conn_PS2_Mini_Din_6; PS2
J2: HDMI_conn; HDMI_connector_19
J3: Conn_RCA_Audio; CUI_RCJ-013-Min
J4: Conn_NConfig; PinHeader_1x01_P2.54mm_Vertical
J5: Conn_RCA_Video; CUI_RCJ-013-Min
J6: Conn_Stacked_USB; USB_A_Wuerth_61400826021_Horizontal_Stacked
J9: Conn_UART_Ext; PinSocket_1x03_P2.54mm_Vertical
J10: Conn_GPIO_Ext; PinSocket_1x10_P2.54mm_Vertical
J11: Conn_SPI_Ext; PinSocket_1x07_P2.54mm_Vertical
J12: Conn_Headphone_Jack; TRRS-PJ-320A
J13: Conn_W5500_1; PinSocket_1x06_P2.54mm_Vertical
J14: Conn_W5500_2; PinSocket_1x06_P2.54mm_Vertical
J15: USB_B_Micro; MicroUSB_G30
Q1, Q2: BSS138; SOT-23
R1, R2, R12, R13, R16, R20, R22, R29, R30, R32, R34, R38, R39, R41, R42, R44, R45: 1k; R_0805_2012Metric_Pad1.20x1.40mm_HandSolder
R3, R9, R14, R28, R31, R37, R40, R43, R46: 2k; R_0805_2012Metric_Pad1.20x1.40mm_HandSolder
R4, R5, R6, R7, R8, R10, R11, R15, R17, R19, R33, R70, R73: 10K; R_0805_2012Metric_Pad1.20x1.40mm_HandSolder
R18: 0R; R_0805_2012Metric_Pad1.20x1.40mm_HandSolder
R21, R23, R25, R26, R50, R51, R54, R55, R60, R61, R71, R72: 0; R_0805_2012Metric_Pad1.20x1.40mm_HandSolder
R35, R36, R52, R53, R56, R57: 10k; R_0805_2012Metric_Pad1.20x1.40mm_HandSolder
R47: 1.6k; R_0805_2012Metric_Pad1.20x1.40mm_HandSolder
R48: 100; R_0805_2012Metric_Pad1.20x1.40mm_HandSolder
R49: 75; R_0805_2012Metric_Pad1.20x1.40mm_HandSolder
R58, R59: 470; R_0805_2012Metric_Pad1.20x1.40mm_HandSolder
SW1: SW_Push_Rst; SW_Tactile_SPST_Angled_PTS645Vx39-2LFS
SW2: SW_Slide; SW_DIP_SPSTx04_Slide_6.7x11.72mm_W8.61mm_P2.54mm_LowProfile
SW3: SW_Push_Config; SW_Tactile_SPST_Angled_PTS645Vx39-2LFS
SW4: SW_Power; SS12D06
U1, U6: SRV05-4; SOT-23-6
U2, U3: CH376T; SSOP-20_5.3x7.2mm_P0.65mm
U4: Conn_02x32_U7; PinHeader_2x32_P2.54mm_Vertical
U5: Conn_02x32_U8; PinHeader_2x32_P2.54mm_Vertical
U7: W25Q128JVS; SOIC-8_5.23x5.23mm_P1.27mm
U8: ADA4841-1YRJ; SOT-23-6
U9: CH340G; SOIC-16_3.9x9.9mm_P1.27mm
U10: CS4344-CZZ; SOP50P490X110-10N; Manufacturer_Part_Number CS4344-CZZ; Mouser Part Number 777-CS4344-CZZ
Y1, Y2, Y3: 12MHz; Crystal_HC49-4H_Vertical

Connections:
+3V3: C7.1, C8.2, C9.2, C10.2, C11.1, C18.2, C19.1, C20.2, C21.2, C22.1, C24.2, C25.2, J10.2, J11.2, J14.2, J14.3, Q1.1 (G), Q2.1 (G), R1.2, R2.2, R6.2, R7.1, R8.2, R10.1, R11.1, R12.2, R15.2, R16.2, R17.2, R18.1, R22.2, R30.2, R34.2, R35.2, R36.2, R39.2, R41.2, R44.2, R52.2, R53.1, R70.2, R73.2, U2.7 (V3), U2.20 (VCC), U3.7 (V3), U3.20 (VCC), U4.3, U4.4, U5.3, U5.4, U7.8 (VCC), U9.4 (V3), U9.16 (VCC), U10.9 (VA)
+5V: C1.1, C2.1, C16.1, C17.2, C31.2, C32.1, C33.2, C34.1, C35.1, J1.4, J2.18 (+5V), J6.1, J6.5, R4.1, R5.1, SW4.2, U1.5, U4.63, U4.64, U5.63, U5.64, U6.5, U8.5 (~PD), U8.6 (V+)
/D1+: J6.3, R25.2
/D1-: J6.2, R26.2
/D2+: J6.7, R21.2
/D2-: J6.6, R23.2
/PS2_Pin_Clk: J1.5, Q1.3 (D), R4.2
/PS2_Pin_Data: J1.1, Q2.3 (D), R5.2
/Ring1: J12.3, R61.1
/Ring2: J12.4
/UD1+: R25.1, U3.8 (UD+)
/UD1-: R26.1, U3.9 (UD-)
/UD2+: R21.1, U2.8 (UD+)
/UD2-: R23.1, U2.9 (UD-)
/USB_FPGC_D1+: J15.3 (D+), R55.2
/USB_FPGC_D1-: J15.2 (D-), R54.2
/USB_FPGC_D2+: R55.1, U9.5 (UD+)
/USB_FPGC_D2-: R54.1, U9.6 (UD-)
Audio_Mono: J3.1 (In), J12.2, R60.1
BTN_RST: R7.2, SW1.1, U4.15
CH376_1_CLK: R70.1, R71.1, U4.8
CH376_1_CS: U2.13 (~SCS), U4.7
CH376_1_INT: U2.1 (~INT~), U4.10
CH376_1_MISO: U2.16 (SDO), U4.12
CH376_1_MOSI: U2.15 (SDI), U4.11
CH376_1_RST: R19.1, U2.2 (RSTI), U4.9
CH376_2_CLK: R72.1, R73.1, U4.22
CH376_2_CS: U3.13 (~SCS), U4.13
CH376_2_INT: U3.1 (~INT~), U4.19
CH376_2_MISO: U3.16 (SDO), U4.21
CH376_2_MOSI: U3.15 (SDI), U4.20
CH376_2_RST: R33.1, U3.2 (RSTI), U4.17
DAC_D0: R3.1, U5.24
DAC_D1: R14.1, U5.26
DAC_D2: R28.1, U5.28
DAC_D3: R31.1, U5.30
DAC_D4: R37.1, U5.32
DAC_D5: R40.1, U5.34
DAC_D6: R43.1, U5.36
DAC_D7: R46.1, U5.38
Ext_CLK: J11.5, U5.11
Ext_CS: J11.6, U5.9
Ext_GP: J11.7, U5.7
Ext_GPIO_0: J10.3, U5.31
Ext_GPIO_1: J10.4, U5.29
Ext_GPIO_2: J10.5, U5.27
Ext_GPIO_3: J10.6, U5.25
Ext_GPIO_4: J10.7, U5.23
Ext_GPIO_5: J10.8, U5.21
Ext_GPIO_6: J10.9, U5.19
Ext_GPIO_7: J10.10, U5.17
Ext_MISO: J11.3, U5.15
Ext_MOSI: J11.4, U5.13
Ext_RX: J9.3, R36.1, U4.34
Ext_TX: J9.2, R35.1, U4.32
FPGC_DTR: U4.53, U9.13 (~DTR)
FPGC_RX: R51.2, U4.51
FPGC_TX: R50.1, U4.49
Flash_CLK: U4.43, U7.6 (CLK)
Flash_CS: U4.50, U7.1 (~CS)
Flash_HOLD_IO3: U4.39, U7.7 (IO3)
Flash_MISO_IO1: U4.45, U7.2 (DO(IO1))
Flash_MOSI_IO0: U4.41, U7.5 (DI(IO0))
Flash_WP_IO2: U4.47, U7.3 (IO2)
GND: C1.2, C2.2, C4.2, C5.2, C6.2, C7.2, C8.1, C9.1, C10.1, C11.2, C12.2, C13.1, C14.2, C15.1, C16.2, C17.1, C18.1, C19.2, C20.1, C21.1, C22.2, C24.1, C25.1, C27.2, C28.1, C29.1, C30.2, C31.1, C32.2, C33.1, C34.2, C35.2, J1.3, J2.2 (D2S), J2.5 (D1S), J2.8 (D0S), J2.11 (CKS), J2.17 (GND), J2.SH, J3.2 (Ext), J5.2 (Ext), J6.4, J6.8, J6.9, J9.1, J10.1, J11.1, J12.1, J13.1, J13.2, J14.1, J15.5 (GND), J15.6 (Shield), R9.2, R19.2, R33.2, R47.2, R56.1, R57.2, SW1.2, SW2.5, SW2.6, SW2.7, SW2.8, SW3.2, SW4.4, U1.2, U2.3 (~SPI~), U2.10 (GND), U3.3 (~SPI~), U3.10 (GND), U4.1, U4.2, U4.5, U4.6, U4.61, U4.62, U5.1, U5.2, U5.5, U5.6, U5.61, U5.62, U6.2, U7.4 (GND), U8.2 (V-), U9.1 (GND), U10.8 (GND)
HDMI_CLK+: J2.10 (CK+), U1.4, U5.55
HDMI_CLK-: J2.12 (CK-), U1.3, U5.56
HDMI_D0+: J2.7 (D0+), U1.1, U5.53
HDMI_D0-: J2.9 (D0-), U1.6, U5.54
HDMI_D1+: J2.4 (D1+), U5.51, U6.4
HDMI_D1-: J2.6 (D1-), U5.52, U6.3
HDMI_D2+: J2.1 (D2+), U5.49, U6.1
HDMI_D2-: J2.3 (D2-), U5.50, U6.6
I2S_LRCLK: U4.31, U10.3 (LRCK)
I2S_MCLK: U4.29, U10.4 (MCLK)
I2S_SCLK: U4.33, U10.2 (~DEM~/SCLK)
I2S_SDIN: U4.35, U10.1 (SDIN)
LED_Booted: D1.1 (K), U4.23
LED_Eth: D2.1 (K), U5.16
LED_FSX: D9.1 (K), U5.12
LED_Flash: D3.1 (K), U5.20
LED_I2S: D10.1 (K), U5.10
LED_PS2: D6.1 (K), U5.8
LED_SPImode: D8.1 (K), U5.18
LED_USB0: D4.1 (K), U4.25
LED_USB1: D5.1 (K), U5.22
LED_VideoOutput: D7.1 (K), U5.14
unnamed: C3.1, R48.2, R49.1, U8.1
unnamed: C3.2, R48.1, U8.4 (-)
unnamed: C4.1, C5.1, U10.5 (VQ)
unnamed: C6.1, U10.6 (FILT+)
unnamed: C12.1, U2.12 (XO), Y1.2
unnamed: C13.2, U2.11 (XI), Y1.1
unnamed: C14.1, U3.12 (XO), Y2.2
unnamed: C15.2, U3.11 (XI), Y2.1
unnamed: C23.1, U10.10 (AOUTR)
unnamed: C23.2, R56.2, R58.2
unnamed: C26.1, U10.7 (AOUTL)
unnamed: C26.2, R57.1, R59.2
unnamed: C27.1, U9.8 (XO), Y3.2
unnamed: C28.2, U9.7 (XI), Y3.1
unnamed: C29.2, R58.1, R60.2
unnamed: C30.1, R59.1, R61.2
unnamed: D1.2 (A), R1.1
unnamed: D2.2 (A), R2.1
unnamed: D3.2 (A), R12.1
unnamed: D4.2 (A), R16.1
unnamed: D5.2 (A), R22.1
unnamed: D6.2 (A), R30.1
unnamed: D7.2 (A), R34.1
unnamed: D8.2 (A), R39.1
unnamed: D9.2 (A), R41.1
unnamed: D10.2 (A), R44.1
unnamed: D11.1 (K), R50.2, U9.3 (RXD)
unnamed: D11.2 (A), R52.1
unnamed: D12.1 (K), R51.1, U9.2 (TXD)
unnamed: D12.2 (A), R53.2
unnamed: F1.1, SW4.1
unnamed: F1.2, J15.1 (VBUS)
unnamed: J4.1, R18.2, SW3.1
unnamed: J5.1 (In), R49.2
unnamed: R3.2, R9.1, R13.1
unnamed: R13.2, R14.2, R20.1
unnamed: R20.2, R28.2, R29.1
unnamed: R29.2, R31.2, R32.1
unnamed: R32.2, R37.2, R38.1
unnamed: R38.2, R40.2, R42.1
unnamed: R42.2, R43.2, R45.1
unnamed: R45.2, R46.2, R47.1, U8.3 (+)
unnamed: R71.2, U2.14 (SCK)
unnamed: R72.2, U3.14 (SCK)
PS2_CLK: Q1.2 (S), R10.2, U4.26
PS2_Data: Q2.2 (S), R11.2, U4.28
SW_1: R17.1, SW2.4, U4.24
SW_2: R15.1, SW2.3, U4.18
SW_3: R8.1, SW2.2, U4.16
SW_4: R6.1, SW2.1, U4.14
W5500_CLK: J13.4, U4.59
W5500_CS: J13.5, U4.58
W5500_INT: J13.6, U4.57
W5500_MISO: J14.6, U4.55
W5500_MOSI: J13.3, U4.60
W5500_RST: J14.5, U4.56

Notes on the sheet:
CH340G/C USB Serial
IO Headers
PS2 with level shifter
CH376T 2x USB Host
I2S-Audio
SPI Flash
W5500 Header
Buttons
FPGA Headers
LEDs
HDMI OUT
8bit DAC (NTSC Video)

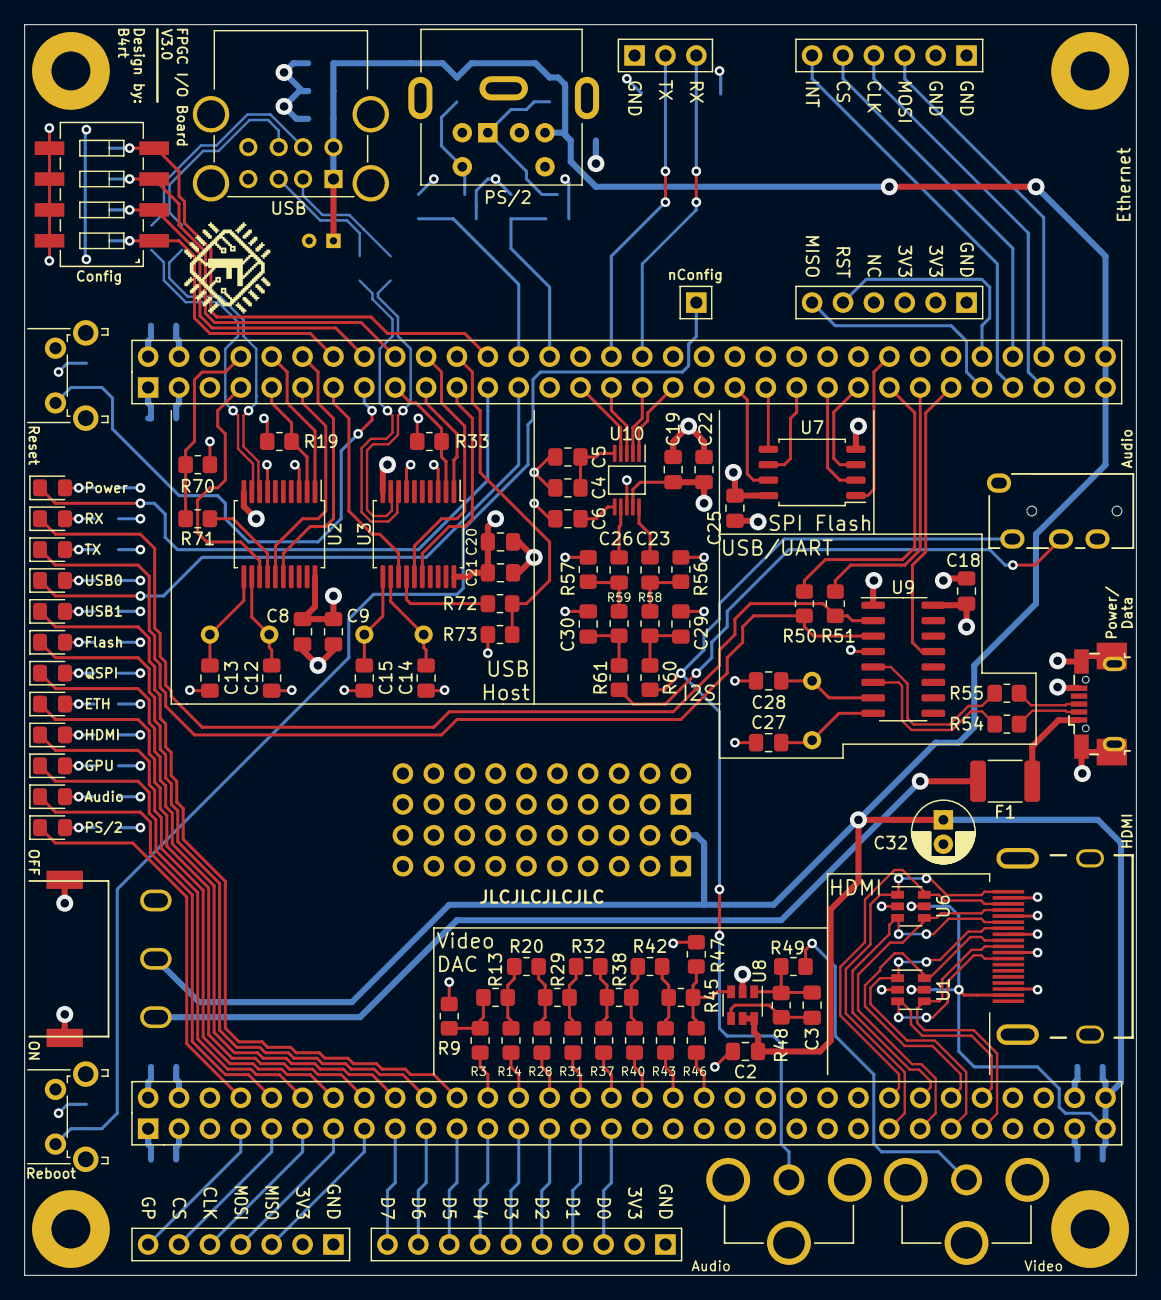
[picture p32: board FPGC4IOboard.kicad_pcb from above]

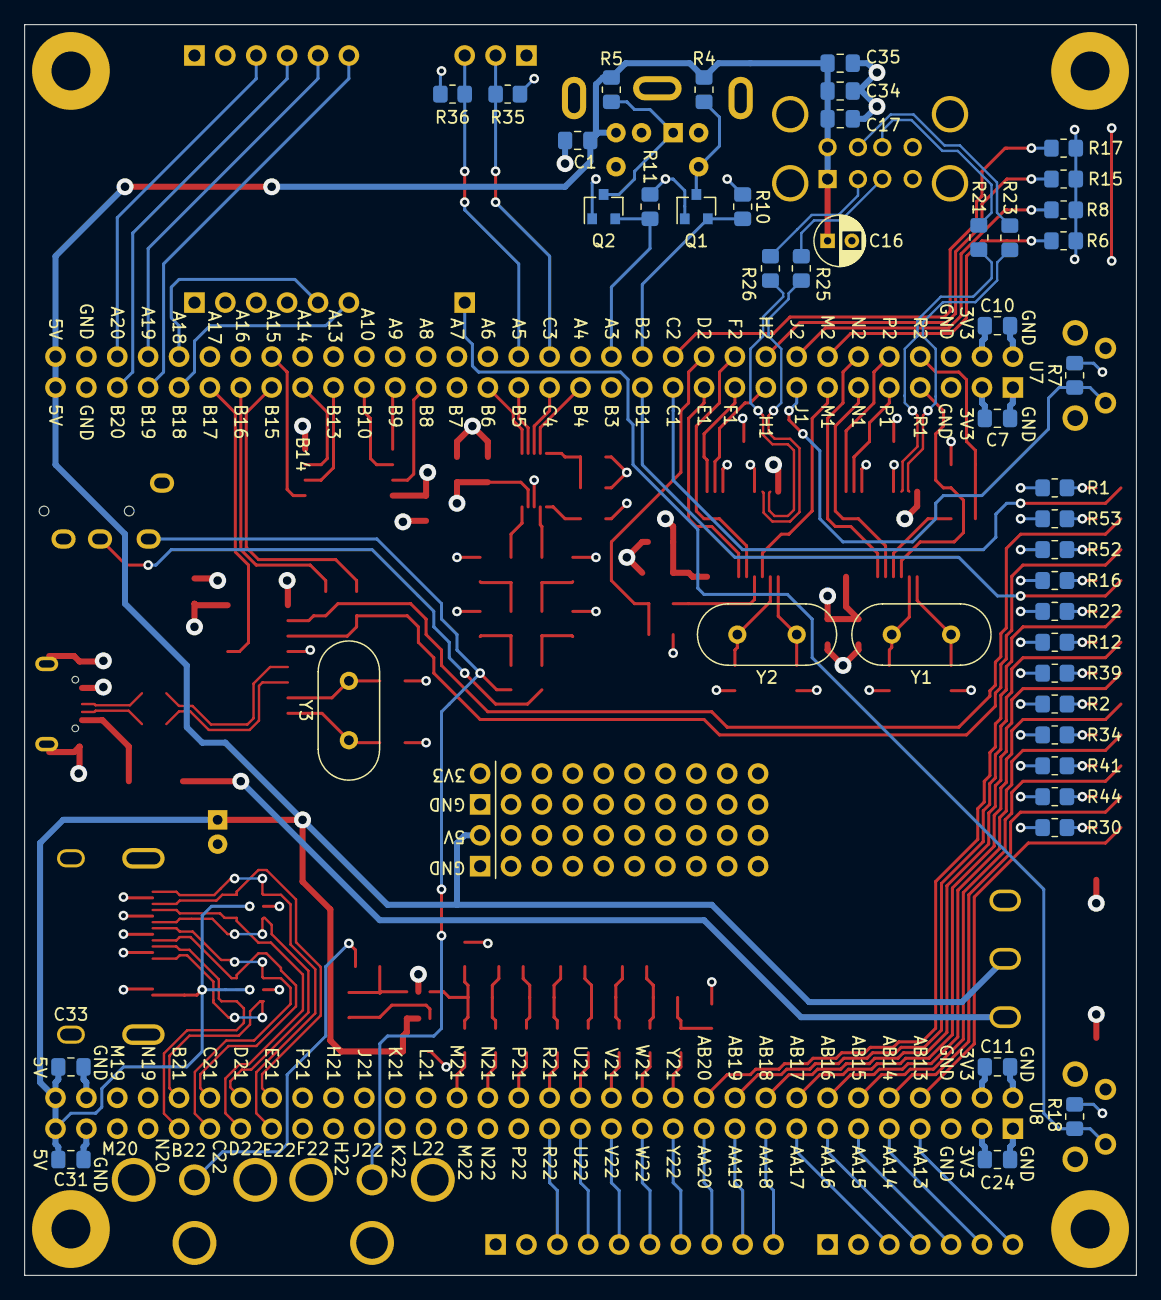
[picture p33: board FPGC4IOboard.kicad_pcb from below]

Board: 4 copper layers, 91.4 x 102.9 mm, 144 parts (44 on the bottom side), 142 nets.

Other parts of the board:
LOGO: LOGO

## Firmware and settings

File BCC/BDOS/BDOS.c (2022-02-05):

/* Bart's Drive Operating System(BDOS)
* A relatively simple OS that allows for some basic features including:
* - Running a single user program with full hardware control
* - Some system calls
* - A basic shell
* - Network loaders for sending data and controlling the FPGC
* - HID fifo including USB keyboard driver
*/


/* List of reserved stuff:
- Timer2 is used for USB keyboard polling, even when a user program is running
- Socket 7 is used for netHID
*/


/*
* Defines (also might be used by included libraries below)
*/

// As of writing, BCC assigns 4 memory addresses to ints, so we should use chars instead
// However, this is confusing, so we typedef it to word, since that is what it basically is
#define word char

#define SYSCALL_RETVAL_ADDR 0x200000    // address for system call communication with user program
#define FS_LDIR_FNAME_ADDR  0x210000    // address for filename list in ldir command
#define FS_LDIR_FSIZE_ADDR  0x218000    // address for filesize list in ldir command
#define TEMP_ADDR           0x220000    // address for (potentially) large temporary outputs/buffers
#define RUN_ADDR            0x400000    // address of loaded user program

#define FS_PATH_MAX_LENGHT  256         // max length of a path

// Interrupt IDs for extended interrupt handler
#define INTID_TIMER2  0x0
#define INTID_TIMER3  0x1
#define INTID_PS2     0x2
#define INTID_UART1   0x3
#define INTID_UART2   0x4

// System call IDs
#define SYSCALL_FIFO_AVAILABLE  1
#define SYSCALL_FIFO_READ       2
#define SYSCALL_PRINT_C_CONSOLE 3
#define SYSCALL_GET_ARGS        4 // get arguments for executed program
#define SYSCALL_GET_PATH        5 // get OS path
#define SYSCALL_GET_USB_KB_BUF  6 // get the 8 bytes of the USB keyboard buffer


/*
* Global vars (also might be used by included libraries below)
*/

// Flag that indicates whether a user program is running
word BDOS_userprogramRunning = 0;

// Path variable and its backup variable
char SHELL_path[FS_PATH_MAX_LENGHT];
char SHELL_pathBackup[FS_PATH_MAX_LENGHT];


/*
* Function prototypes, so they can be called in all libraries below
*/

// These functions are used by some of the other libraries
void BDOS_Backup();
void BDOS_Restore();
void SHELL_clearCommand();


/*
* Included libraries
*/

// Data includes
#include "data/ASCII_BW.c"
#include "data/PS2SCANCODES.c"
#include "data/USBSCANCODES.c"

// Code includes
#include "lib/stdlib.c"
#include "lib/math.c"
#include "lib/gfx.c"
#include "lib/hidfifo.c"
#include "lib/ps2.c"
#include "lib/usbkeyboard.c"
#include "lib/fs.c"
#include "lib/wiz5500.c"
#include "lib/netloader.c"
#include "lib/nethid.c"
#include "lib/shell.c"


/*
* Functions
*/

// Initializes CH376 and mounts drive
// returns 1 on success
word BDOS_Init_FS()
{
    if (FS_init() != FS_ANSW_RET_SUCCESS)
    {
        GFX_PrintConsole("Error initializing CH376 for FS");
        return 0;
    }

    delay(10);

    if (FS_connectDrive() != FS_ANSW_USB_INT_SUCCESS)
    {
        GFX_PrintConsole("Could not mount drive");
        return 0;
    }
    return 1;
}

// Clears all VRAM
//  and copies the default ASCII pattern table and palette table
// also resets the cursor
void BDOS_Reinit_VRAM()
{
    GFX_initVram();
    GFX_copyPaletteTable((word)DATA_PALETTE_DEFAULT);
    GFX_copyPatternTable((word)DATA_ASCII_DEFAULT);
    GFX_cursor = 0;
}

// Initialize the W5500
void BDOS_initNetwork()
{
    word ip_addr[4] = {192, 168, 0, 213};

    word gateway_addr[4] = {192, 168, 0, 1};

    word mac_addr[6] = {0xDE, 0xAD, 0xBE, 0xEF, 0x24, 0x64};

    word sub_mask[4] = {255, 255, 255, 0};

    wiz_Init(ip_addr, gateway_addr, mac_addr, sub_mask);
}

// Backup important things before running a user program
void BDOS_Backup()
{
    // TODO look into what to backup
}

// Restores certain things when returning from a user program
void BDOS_Restore()
{
    // restore graphics (trying to keep text in window plane)
    GFX_copyPaletteTable((word)DATA_PALETTE_DEFAULT);
    GFX_copyPatternTable((word)DATA_ASCII_DEFAULT);
    GFX_clearBGtileTable();
    GFX_clearBGpaletteTable();
    GFX_clearWindowpaletteTable();
    GFX_clearSprites();

    // restore netloader
    NETLOADER_init(NETLOADER_SOCKET);
}

// Main BDOS code
int main() 
{
    // all kinds of initialisations

    BDOS_userprogramRunning = 0; // indicate that no user program is running

    BDOS_Reinit_VRAM(); // start with loading ASCII table and set palette
    
    GFX_PrintConsole("Starting BDOS\n"); // print welcome message

    GFX_PrintConsole("Init network...");
    BDOS_initNetwork();
    GFX_PrintConsole("DONE\n");

    GFX_PrintConsole("Init netloader...");
    NETLOADER_init(NETLOADER_SOCKET);
    GFX_PrintConsole("DONE\n");

    GFX_PrintConsole("Init netHID...");
    NETHID_init(NETHID_SOCKET);
    GFX_PrintConsole("DONE\n");

    GFX_PrintConsole("Init USB keyboard...");
    USBkeyboard_init();
    GFX_PrintConsole("DONE\n");

    GFX_PrintConsole("Init filesystem...");
    if (!BDOS_Init_FS())
        return 0;
    GFX_PrintConsole("DONE\n");

    // init shell
    SHELL_init();

    // main loop
    while (1)
    {
        SHELL_loop();                       // update the shell state
        NETLOADER_loop(NETLOADER_SOCKET);   // update the netloader state
    }

    return 1;
}


// System call handler
// Returns at the same address it reads the command from
void syscall()
{
    word* p = (word*) SYSCALL_RETVAL_ADDR;
    word ID = p[0];

    switch(ID)
    {
        case SYSCALL_FIFO_AVAILABLE:
            p[0] = HID_FifoAvailable();
            break;
        case SYSCALL_FIFO_READ:
            p[0] = HID_FifoRead();
            break;
        case SYSCALL_PRINT_C_CONSOLE:
            GFX_PrintcConsole(p[1]);
            p[0] = 0;
            break;
        case SYSCALL_GET_ARGS:
            p[0] = SHELL_command;
            break;
        case SYSCALL_GET_PATH:
            p[0] = SHELL_pathBackup;
            break;
        case SYSCALL_GET_USB_KB_BUF:
            p[0] = USBkeyboard_buffer_parsed;
            break;
        default:
            p[0] = 0;
            break;
    }
}

// Timer1 interrupt handler
void int1()
{
    timer1Value = 1; // notify ending of timer1

    // check if a user program is running
    if (BDOS_userprogramRunning)
    {
        // call int1() of user program
        asm(
            "; backup registers\n"
            "push r1\n"
            "push r2\n"
            "push r3\n"
            "push r4\n"
            "push r5\n"
            "push r6\n"
            "push r7\n"
            "push r8\n"
            "push r9\n"
            "push r10\n"
            "push r11\n"
            "push r12\n"
            "push r13\n"
            "push r14\n"
            "push r15\n"

            "savpc r1\n"
            "push r1\n"
            "jump 0x400001\n"

            "; restore registers\n"
            "pop r15\n"
            "pop r14\n"
            "pop r13\n"
            "pop r12\n"
            "pop r11\n"
            "pop r10\n"
            "pop r9\n"
            "pop r8\n"
            "pop r7\n"
            "pop r6\n"
            "pop r5\n"
            "pop r4\n"
            "pop r3\n"
            "pop r2\n"
            "pop r1\n"
            );
        return;
    }
    else // code to only run when not running a user program
    {
        
    }
}

// Extended interrupt handler
// use getIntID to get the id of the interrupt
void int2()
{
    int i = getIntID();
    switch(i)
    {
        case INTID_PS2:
            PS2_HandleInterrupt(); // handle PS2 interrupt
            break;

        case INTID_TIMER2:
            USBkeyboard_HandleInterrupt(); // handle USB keyboard interrupt
            break;
    }

    // check if a user program is running
    if (BDOS_userprogramRunning)
    {
        // call int2() of user program
        asm(
            "; backup registers\n"
            "push r1\n"
            "push r2\n"
            "push r3\n"
            "push r4\n"
            "push r5\n"
            "push r6\n"
            "push r7\n"
            "push r8\n"
            "push r9\n"
            "push r10\n"
            "push r11\n"
            "push r12\n"
            "push r13\n"
            "push r14\n"
            "push r15\n"

            "savpc r1\n"
            "push r1\n"
            "jump 0x400002\n"

            "; restore registers\n"
            "pop r15\n"
            "pop r14\n"
            "pop r13\n"
            "pop r12\n"
            "pop r11\n"
            "pop r10\n"
            "pop r9\n"
            "pop r8\n"
            "pop r7\n"
            "pop r6\n"
            "pop r5\n"
            "pop r4\n"
            "pop r3\n"
            "pop r2\n"
            "pop r1\n"
            );
        return;
    }
    else // code to only run when not running a user program
    {
        
    }
}

// UART0 (TTYUSB) interrupt handler
void int3()
{
    // check if a user program is running
    if (BDOS_userprogramRunning)
    {
        // call int3() of user program
        asm(
            "; backup registers\n"
            "push r1\n"
            "push r2\n"
            "push r3\n"
            "push r4\n"
            "push r5\n"
            "push r6\n"
            "push r7\n"
            "push r8\n"
            "push r9\n"
            "push r10\n"
            "push r11\n"
            "push r12\n"
            "push r13\n"
            "push r14\n"
            "push r15\n"

            "savpc r1\n"
            "push r1\n"
            "jump 0x400003\n"

            "; restore registers\n"
            "pop r15\n"
            "pop r14\n"
            "pop r13\n"
            "pop r12\n"
            "pop r11\n"
            "pop r10\n"
            "pop r9\n"
            "pop r8\n"
            "pop r7\n"
            "pop r6\n"
            "pop r5\n"
            "pop r4\n"
            "pop r3\n"
            "pop r2\n"
            "pop r1\n"
            );
        return;
    }
    else // code to only run when not running a user program
    {
        
    }
}

// GFX framedrawn interrupt handler
// is called every frame, which is ~60 times per second
void int4()
{
    if (NETHID_isInitialized == 1)
    {
        // check using CS if we are not interrupting any critical access to the W5500
        word* spi3ChipSelect = (word*) 0xC02732;
        if (*spi3ChipSelect == 1)
        {
            NETHID_loop(NETHID_SOCKET); // look for an input sent to netHID
        }
    }

    // check if a user program is running
    if (BDOS_userprogramRunning)
    {
        // call int4() of user program
        asm(
            "; backup registers\n"
            "push r1\n"
            "push r2\n"
            "push r3\n"
            "push r4\n"
            "push r5\n"
            "push r6\n"
            "push r7\n"
            "push r8\n"
            "push r9\n"
            "push r10\n"
            "push r11\n"
            "push r12\n"
            "push r13\n"
            "push r14\n"
            "push r15\n"

            "savpc r1\n"
            "push r1\n"
            "jump 0x400004\n"

            "; restore registers\n"
            "pop r15\n"
            "pop r14\n"
            "pop r13\n"
            "pop r12\n"
            "pop r11\n"
            "pop r10\n"
            "pop r9\n"
            "pop r8\n"
            "pop r7\n"
            "pop r6\n"
            "pop r5\n"
            "pop r4\n"
            "pop r3\n"
            "pop r2\n"
            "pop r1\n"
            );
        return;
    }
    else // code to only run when not running a user program
    {
        
    }
}

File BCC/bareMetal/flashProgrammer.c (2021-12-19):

// Flash programmer
// Tool to flash the SPI flash chip

#define word char

#include "data/ASCII_BW.c"
#include "lib/math.c"
#include "lib/stdlib.c"
#include "lib/gfx.c"


#define COMMAND_IDLE                    0
#define COMMAND_FLASH_READ              114 // 'r'
#define COMMAND_FLASH_ERASE_BLOCK       101 // 'e'
#define COMMAND_FLASH_WRITE             119 // 'w'
#define COMMAND_FILL_BUFFER             98  // 'b'
#define COMMAND_DONE                    100 // 'd'

#define BLOCK_SIZE 32768
#define SECTOR_SIZE 4096
#define PAGE_SIZE 256
#define COMMAND_SIZE 8


// the current command the program is busy with
// if idle, should listen to UART for new command
word currentCommand;

// UART buffer that stores a single command
word UARTbufferIndex = 0;
word UARTbuffer[COMMAND_SIZE];

// Buffer of a page to write
word pageBufferIndex = 0;
word pageBuffer[PAGE_SIZE];

/* Description of commands:

READ x(24bit) Bytes from address y(24bit):
    b0: 'r'
    b1: x[23:16]
    b2: x[15:8]
    b3: x[7:0]
    b4: y[23:16]
    b5: y[15:8]
    b6: y[7:0]
    b7: '\n' (indicate end of command)
*/

void initVram()
{
    GFX_initVram(); // clear all VRAM
    GFX_copyPaletteTable((word)DATA_PALETTE_DEFAULT);
    GFX_copyPatternTable((word)DATA_ASCII_DEFAULT);

    GFX_cursor = 0;
}

// Workaround for defines in ASM
void SpiFlash_asmDefines()
{
    asm(
        "define W5500_SPI0_CS_ADDR = 0xC02729 ; address of SPI0_CS\n"
        "define W5500_SPI0_ADDR = 0xC02728    ; address of SPI0\n"
        );
}

// Sets SPI0_CS low
void SpiBeginTransfer()
{
    asm(
        "; backup regs\n"
        "push r1\n"
        "push r2\n"

        "load32 W5500_SPI0_CS_ADDR r2       ; r2 = W5500_SPI0_CS_ADDR\n"

        "load 0 r1                          ; r1 = 0 (enable)\n"
        "write 0 r2 r1                      ; write to SPI0_CS\n"

        "; restore regs\n"
        "pop r2\n"
        "pop r1\n"
        );
}

// Sets SPI0_CS high
void SpiEndTransfer()
{
    asm(
        "; backup regs\n"
        "push r1\n"
        "push r2\n"

        "load32 W5500_SPI0_CS_ADDR r2       ; r2 = W5500_SPI0_CS_ADDR\n"

        "load 1 r1                          ; r1 = 1 (disable)\n"
        "write 0 r2 r1                      ; write to SPI0_CS\n"

        "; restore regs\n"
        "pop r2\n"
        "pop r1\n"
        );
}

// write dataByte and return read value
// write 0x00 for a read
// Writes byte over SPI0
word SpiTransfer(word dataByte)
{
    word retval = 0;
    asm(
        "load32 W5500_SPI0_ADDR r2          ; r2 = W5500_SPI0_ADDR\n"
        "write 0 r2 r4                      ; write r4 over SPI0\n"
        "read 0 r2 r2                       ; read return value\n"
        "write -4 r14 r2                    ; write to stack to return\n"
        );

    return retval;
}



// inits SPI by enabling SPI0 and resetting the chip
void initSPI()
{
    // already set CS high before enabling SPI0
    SpiEndTransfer();

    // enable SPI0
    word *p = (word *) 0xC0272A; // set address (SPI0 enable)
    *p = 1; // write value
    delay(10);

    // reset to get out of continuous read mode
    SpiBeginTransfer();
    SpiTransfer(0x66);
    SpiEndTransfer();
    delay(1);
    SpiBeginTransfer();
    SpiTransfer(0x99);
    SpiEndTransfer();
    delay(1);
    SpiBeginTransfer();
    SpiTransfer(0x66);
    SpiEndTransfer();
    delay(1);
    SpiBeginTransfer();
    SpiTransfer(0x99);
    SpiEndTransfer();
    delay(1);
}



// Should print 0xEF as Winbond device ID, and 0x17 for W25Q128
void readDeviceID()
{
    SpiBeginTransfer();
    SpiTransfer(0x90);
    SpiTransfer(0);
    SpiTransfer(0);
    SpiTransfer(0);
    word manufacturer = SpiTransfer(0);
    word deviceID = SpiTransfer(0);
    SpiEndTransfer();

    char b[10];
    itoah(manufacturer, b);
    GFX_PrintConsole("Chip manufacturer: ");
    GFX_PrintConsole(b);
    GFX_PrintConsole("\n");

    GFX_PrintConsole("Chip ID: ");
    itoah(deviceID, b);
    GFX_PrintConsole(b);
    GFX_PrintConsole("\n");
}


void readAndPrint(word len, word addr24, word addr16, word addr8)
{
    word l = len;
    word a24 = addr24;
    word a16 = addr16;
    word a8 = addr8;

    SpiBeginTransfer();
    SpiTransfer(0x03);
    SpiTransfer(a24);
    SpiTransfer(a16);
    SpiTransfer(a8);


    word i;
    for (i = 0; i < l; i++)
    {
        uprintc(SpiTransfer(0x00));
    }

    SpiEndTransfer();
}


/* Returns status register 1 2 or 3, depending on the value of reg (1, 2 or 3)

Status register description:

Register 1: (default: 0x0)
    b7: Status Register Protect 0
    b6: Sector Protect Bit
    b5: Top/Bottom Protect Bit
    b4: Block Protect Bit 2
    b3: Block Protect Bit 1
    b2: Block Protect Bit 0
    b1: Write Enable Latch
    b0: BUSY: Erase/Write in Progress

Register 2: (default: 0x2)
    b7: Suspend Status
    b6: Complement Protect
    b5: Security Register Lock bit 2
    b4: Security Register Lock bit 1
    b3: Security Register Lock bit 0
    b2: Reserved
    b1: Quad Enable
    b0: Status Register Protect 1

Register 3: (default: 0x60)
    b7: Reserved
    b6: Output Driver Strength bit 1
    b5: Output Driver Strength bit 0
    b4: Reserved
    b3: Reserved
    b2: Write Protect Selection
    b1: Reserved
    b0: Reserved


*/

word readStatusRegister(word reg)
{
    SpiBeginTransfer();

    if (reg == 2)
        SpiTransfer(0x35);
    else if (reg == 3)
        SpiTransfer(0x15);
    else
        SpiTransfer(0x05);

    word status = SpiTransfer(0);
    SpiEndTransfer();

    return status;
}



void enableWrite()
{
    SpiBeginTransfer();
    SpiTransfer(0x06);
    SpiEndTransfer();
}


// Executes chip erase operation
// TAKES AT LEAST 20 SECONDS!
// Returns 1 on success
word chipErase()
{
    enableWrite();

    word status = readStatusRegister(1);

    // Check if write is enabled
    if ((status & 0x2) == 0)
        return 0;

    // Send command
    SpiBeginTransfer();
    SpiTransfer(0xC7);
    SpiEndTransfer();


    // Wait for busy bit to be 0
    status = 1;

    while((status & 0x1) == 1) 
    {
        status = readStatusRegister(1);
    }

    return 1;
}



// Executes 32KiB block erase operation
// Erases the 32KiB block that contains the given byte address
// Returns 1 on success
word blockErase(word addr24, word addr16, word addr8)
{

    word a24 = addr24;
    word a16 = addr16;
    word a8 = addr8;

    enableWrite();

    word status = readStatusRegister(1);

    // Check if write is enabled
    if ((status & 0x2) == 0)
        return 0;

    // Send command
    SpiBeginTransfer();
    SpiTransfer(0x52);
    SpiTransfer(a24);
    SpiTransfer(a16);
    SpiTransfer(a8);
    SpiEndTransfer();


    // Wait for busy bit to be 0
    status = 1;

    while((status & 0x1) == 1) 
    {
        status = readStatusRegister(1);
    }

    return 1;
}
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

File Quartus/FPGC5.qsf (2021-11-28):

# -------------------------------------------------------------------------- #
#
# Copyright (C) 1991-2012 Altera Corporation
# Your use of Altera Corporation's design tools, logic functions
# and other software and tools, and its AMPP partner logic
# functions, and any output files from any of the foregoing
# (including device programming or simulation files), and any
# associated documentation or information are expressly subject
# to the terms and conditions of the Altera Program License
# Subscription Agreement, Altera MegaCore Function License
# Agreement, or other applicable license agreement, including,
# without limitation, that your use is for the sole purpose of
# programming logic devices manufactured by Altera and sold by
# Altera or its authorized distributors.  Please refer to the
# applicable agreement for further details.
#
# -------------------------------------------------------------------------- #
#
# Quartus II 64-Bit
# Version 12.1 Build 177 11/07/2012 SJ Full Version
# Date created = 09:34:42  September 06, 2015
#
# -------------------------------------------------------------------------- #
#
# Notes:
#
# 1) The default values for assignments are stored in the file:
#		FPGC5_assignment_defaults.qdf
#    If this file doesn't exist, see file:
#		assignment_defaults.qdf
#
# 2) Altera recommends that you do not modify this file. This
#    file is updated automatically by the Quartus II software
#    and any changes you make may be lost or overwritten.
#
# -------------------------------------------------------------------------- #


set_global_assignment -name FAMILY "Cyclone IV E"
set_global_assignment -name DEVICE EP4CE15F23C8
set_global_assignment -name TOP_LEVEL_ENTITY FPGC5
set_global_assignment -name ORIGINAL_QUARTUS_VERSION 20.1.1
set_global_assignment -name PROJECT_CREATION_TIME_DATE "16:23:14  JUNE 23, 2021"
set_global_assignment -name LAST_QUARTUS_VERSION "20.1.0 Lite Edition"
set_global_assignment -name PROJECT_OUTPUT_DIRECTORY output_files
set_global_assignment -name MIN_CORE_JUNCTION_TEMP 0
set_global_assignment -name MAX_CORE_JUNCTION_TEMP 85
set_global_assignment -name DEVICE_FILTER_PACKAGE FBGA
set_global_assignment -name DEVICE_FILTER_PIN_COUNT 484
set_global_assignment -name DEVICE_FILTER_SPEED_GRADE 8
set_global_assignment -name ERROR_CHECK_FREQUENCY_DIVISOR 1
set_global_assignment -name EDA_SIMULATION_TOOL "ModelSim (Verilog)"
set_global_assignment -name EDA_OUTPUT_DATA_FORMAT "VERILOG HDL" -section_id eda_simulation
set_global_assignment -name USE_CONFIGURATION_DEVICE OFF
set_global_assignment -name CRC_ERROR_OPEN_DRAIN OFF
set_global_assignment -name STRATIX_DEVICE_IO_STANDARD "3.3-V LVTTL"
set_global_assignment -name CYCLONEII_RESERVE_NCEO_AFTER_CONFIGURATION "USE AS REGULAR IO"
set_global_assignment -name RESERVE_DATA0_AFTER_CONFIGURATION "USE AS REGULAR IO"
set_global_assignment -name RESERVE_DATA1_AFTER_CONFIGURATION "USE AS REGULAR IO"
set_global_assignment -name RESERVE_FLASH_NCE_AFTER_CONFIGURATION "USE AS REGULAR IO"
set_global_assignment -name RESERVE_DCLK_AFTER_CONFIGURATION "USE AS REGULAR IO"
set_global_assignment -name OUTPUT_IO_TIMING_NEAR_END_VMEAS "HALF VCCIO" -rise
set_global_assignment -name OUTPUT_IO_TIMING_NEAR_END_VMEAS "HALF VCCIO" -fall
set_global_assignment -name OUTPUT_IO_TIMING_FAR_END_VMEAS "HALF SIGNAL SWING" -rise
set_global_assignment -name OUTPUT_IO_TIMING_FAR_END_VMEAS "HALF SIGNAL SWING" -fall
set_global_assignment -name EDA_TIME_SCALE "1 ps" -section_id eda_simulation
set_global_assignment -name EDA_TEST_BENCH_ENABLE_STATUS TEST_BENCH_MODE -section_id eda_simulation
set_global_assignment -name POWER_PRESET_COOLING_SOLUTION "23 MM HEAT SINK WITH 200 LFPM AIRFLOW"
set_global_assignment -name POWER_BOARD_THERMAL_MODEL "NONE (CONSERVATIVE)"
set_global_assignment -name PARTITION_NETLIST_TYPE SOURCE -section_id Top
set_global_assignment -name PARTITION_FITTER_PRESERVATION_LEVEL PLACEMENT_AND_ROUTING -section_id Top
set_global_assignment -name PARTITION_COLOR 16764057 -section_id Top
set_location_assignment PIN_T2 -to clock
set_location_assignment PIN_J1 -to nreset
set_location_assignment PIN_E4 -to led
set_location_assignment PIN_AB4 -to SDRAM_WEn
set_location_assignment PIN_W7 -to SDRAM_DQM[0]
set_location_assignment PIN_AB3 -to SDRAM_RASn
set_location_assignment PIN_AA5 -to SDRAM_DQM[1]
set_location_assignment PIN_AA3 -to SDRAM_CSn
set_location_assignment PIN_Y6 -to SDRAM_CLK
set_location_assignment PIN_W6 -to SDRAM_CKE
set_location_assignment PIN_AA4 -to SDRAM_CASn
set_location_assignment PIN_AA10 -to SDRAM_DQ[0]
set_location_assignment PIN_AB9 -to SDRAM_DQ[1]
set_location_assignment PIN_AA9 -to SDRAM_DQ[2]
set_location_assignment PIN_AB8 -to SDRAM_DQ[3]
set_location_assignment PIN_AA8 -to SDRAM_DQ[4]
set_location_assignment PIN_AB7 -to SDRAM_DQ[5]
set_location_assignment PIN_AA7 -to SDRAM_DQ[6]
set_location_assignment PIN_AB5 -to SDRAM_DQ[7]
set_location_assignment PIN_Y7 -to SDRAM_DQ[8]
set_location_assignment PIN_W8 -to SDRAM_DQ[9]
set_location_assignment PIN_Y8 -to SDRAM_DQ[10]
set_location_assignment PIN_V9 -to SDRAM_DQ[11]
set_location_assignment PIN_V10 -to SDRAM_DQ[12]
set_location_assignment PIN_Y10 -to SDRAM_DQ[13]
set_location_assignment PIN_W10 -to SDRAM_DQ[14]
set_location_assignment PIN_V11 -to SDRAM_DQ[15]
set_location_assignment PIN_Y1 -to SDRAM_BA[0]
set_location_assignment PIN_W2 -to SDRAM_BA[1]
set_location_assignment PIN_V2 -to SDRAM_A[0]
set_location_assignment PIN_V1 -to SDRAM_A[1]
set_location_assignment PIN_U2 -to SDRAM_A[2]
set_location_assignment PIN_U1 -to SDRAM_A[3]
set_location_assignment PIN_V3 -to SDRAM_A[4]
set_location_assignment PIN_V4 -to SDRAM_A[5]
set_location_assignment PIN_Y2 -to SDRAM_A[6]
set_location_assignment PIN_AA1 -to SDRAM_A[7]
set_location_assignment PIN_Y3 -to SDRAM_A[8]
set_location_assignment PIN_V5 -to SDRAM_A[9]
set_location_assignment PIN_W1 -to SDRAM_A[10]
set_location_assignment PIN_Y4 -to SDRAM_A[11]
set_location_assignment PIN_V6 -to SDRAM_A[12]
set_location_assignment PIN_B17 -to UART0_dtr
set_location_assignment PIN_B15 -to UART0_out
set_location_assignment PIN_B16 -to UART0_in
set_location_assignment PIN_C3 -to UART2_out
set_location_assignment PIN_A5 -to UART2_in
set_location_assignment PIN_B10 -to SPI0_clk
set_location_assignment PIN_A15 -to SPI0_cs
set_location_assignment PIN_B9 -to SPI0_data
set_location_assignment PIN_B13 -to SPI0_q
set_location_assignment PIN_B14 -to SPI0_wp
set_location_assignment PIN_B8 -to SPI0_hold
set_location_assignment PIN_R2 -to SPI1_clk
set_location_assignment PIN_R1 -to SPI1_cs
set_location_assignment PIN_N1 -to SPI1_mosi
set_location_assignment PIN_N2 -to SPI1_miso
set_location_assignment PIN_P1 -to SPI1_rst
set_location_assignment PIN_P2 -to SPI1_nint
set_location_assignment PIN_D2 -to SPI2_clk
set_location_assignment PIN_M1 -to SPI2_cs
set_location_assignment PIN_F2 -to SPI2_mosi
set_location_assignment PIN_E1 -to SPI2_miso
set_location_assignment PIN_H1 -to SPI2_rst
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

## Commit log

2021-06-23 Init from FPGC4
    [FC68128.step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]
2021-06-24 Added light sleep on idle to save power
2021-06-24 Fixed midiSynth. Few quick fixes to run some uart related scripts on WSL2 via Windows.
    [uartFlasher_win.py]
2021-06-25 userBDOS MIDI program now works (as a test, should make proper audio library. Changed BDOS Alpha to BDOS. Changed command names to ls and cd. Added a warning in BDOS documentation about the used of t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
2021-07-01 FPGC5 now works with SDRAM at 100MHz, tested in hardware. Still quite messy and MU contains extra cycles to latch certain things to prevent combinational loops and to pass timing constraints.
    [FPGC5.qsf]
2021-07-05 New and better nespadreader, fixed bug in MU where bus_done_next would be instantly set when the address was higher than a certain address. Updated output_file. SPI modules are the only ones that sti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
2021-07-05 New SPI reader module. Replaces FastSPI module as well, even though it runs at max half system speed. Still need to do spi reader (qspi flash reader) module
    [FPGC5.qsf]
2021-07-06 Improved MU, much cleaner now. Did not improve on timing and area by much, probably because of the large address selection chain. However, it is now much easier to work in without having to worry too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
2021-07-08 Added compileAndSend script in Assembler. Renamed the simTest file
2021-07-09 Added userBDOS webserver program. Updated BDOS to use the same function for loading a program from storage. Netflasher and uploader now retries up to 5 times on failure with a second delay in between
    [BDOS.c, netFlash.py, netUpload.py]
2021-07-12 UART speed from 115200 to 1MBaud (in HW, Tools and ESP32Synth). Added help command to BDOS. Started on cp command.
2021-07-12 Updated bootloader to not display the 4 in FPGC4. Also fixed graphics bug where the pattern table is not completely copied
    [bootloader.asm]
2021-10-19 Started working on new FPGC5 PCB, starting to move back to linux (already changed some .gtkw paths), added script for creating a RGB332 to NTSC Y Phase Saturation lookup table
    [CUI_DEVICES_RCJ-013.step, FC68128.step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]
2021-10-20 Added 240p color NTSC video output! Can be selected by DIP[1] (selects between HDMI and NTSC). Currently gives timing errors, but works fine in hardware (afaik), need to find a way to tell quartus th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
    [FPGC5.qsf]
2021-10-22 Fixed vertical position of NTSC output. Restored GPIO pin assignments and moved NTSC to the extra pins on the bottom of the PCB. Worked a tiny bit on the new PCB version. Added a cython base version 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
    [FPGC4IOboard.sch]
2021-10-24 Added many connectors and stuffs to new PCB
    [Conn_USB-micro-2.0_socket_right-angle.step, FPGC4IOboard.sch, HDMI.stp]
2021-10-24 Initial version of PCBv3 schema is done
    [CS4344-CZZ.stp, FPGC4IOboard.sch, SS12D06-1.step]
2021-10-24 Ran annotation and fixed led footprints on schema
    [FPGC4IOboard.sch]
2021-10-24 Fixed a bunch of footprints
    [FPGC4IOboard.sch]
2021-10-27 Started on PCB layouting
    [FPGC4IOboard.kicad_pcb, FPGC4IOboard.sch]
2021-11-03 PCB v3 initial routing done. Need to optimize and finish silkscreen layer
    [FPGC4IOboard.kicad_pcb, FPGC4IOboard.sch]
2021-11-05 Basically finished the new PCB design
    [FPGC4IOboard.kicad_pcb, FPGC4IOboard.sch]
2021-11-06 Added gerbers
    [FPGC4IOboard-B_Cu.gbl, FPGC4IOboard-B_Cu.gbr, FPGC4IOboard-B_Mask.gbr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]
2021-11-21 Updated Quartus & Verilog to new PCB (v3) design. Added test code to test both CH376 chips. Added BOM of PCB in HTML. Fixed argument position bug in compileAndSend.sh
    [FPGC5.qsf]
2021-11-27 Added LED visualizers. Fixed some small things like default CS and TX values (also on reset).
    [FPGC5.qsf]
2021-11-30 Assembler now supports .code and .data directives (it moves all .data parts to the end of the program). Assembler now also supports .dl instructions (static label address as data). Assembler now also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
2021-11-30 removed labels from comments in assembler, since it does not work for instructions needing a second pass. Made difference between .rdata and .data, needed for an array of cstrings (pointers). More in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
    [cgb322.c]
2021-11-30 SmallerC backup commit, before trying to change all byte-addressable functionality to word-addressable. If this fails, I could temporarily duplicate .data statements
    [cgb322.c]
2021-11-30 Decided to use a simple hacky fix by duplicating static data to make SmallerC work with B322's word aligned memory, since the priority lies on getting a really solid compiler first, so I can make opt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
    [cgb322.c]
2021-11-30 Added .bss support to assembler. Modified compilerTests/m.c to generate a .bss section
2021-11-30 Interrupts are now working
2021-11-30 Fixed bug in GenReadIdent where I forgot to do a READ after the ADDR2REG. More stuff is working now.
    [cgb322.c]
2021-12-01 Added signed branch instructions to hardware and assembler (untested, but not a big change)
2021-12-01 Made all branch checks signed by default in SmallerC. Added a signed loop testcase. Replaced a lot of tabs with spaces.
    [cgb322.c]
2021-12-02 Fixed some constant bugs in SmallerC. Replaced division and modulo with a function so no more div or mod instructions are generated when compiling SmallerC using itself. Started on replacing some inc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
    [cgb322.c]
2021-12-03 removed instructions from bcc where parts of registers are cut off to 8 or 16 bits. Added file size print in compile script. gfx.c library done for now
2021-12-04 Ported all HID functions to BCC. Improved USB keyboard button hold detection
2021-12-04 Ported FS and shell to BCC. Everything works including system calls/interrupt stuff. Only netloader remains before moving on to the userBDOS programs
2021-12-04 Ported netloader to BCC, adjusted some delay timings for the SPI stuff. BDOS is now fully working (and is faster and smaller)
2021-12-08 More work on porting BCC to FPGC. Made library of stdio replacement code.
    [backend.c]
2021-12-10 Fixed issue where the getBDOS syscall would return garbage because the path backup memory is not initialized together with the path memory. Change HDMIview script because I switched development pc
    [BDOS.c]
2021-12-11 made annotations optional in BCC on FPGC. BCC on FPGC can now compile the webserver.c (although very slow). Added print in getc, since it is a nice progress bar alternative.
2021-12-13 Started on assembler in C. Added newline prints for long .space commands in bcc on fpgc
2021-12-14 Minor project cleanup and changes
    [FC68128.step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]
2021-12-16 Added progress bars in BDOS. Reduced error rate in netloader
    [BDOS.c]
2021-12-18 Created snake userBDOS game. Added syscall for obtaining the parsed usb keyboard buffer, useful for knowing if a certain button is held
2021-12-18 Converted gfx scroll up function to assembly for a huge speedup
2021-12-18 Removed left over debug print in userbdos/lib/sys.c
2021-12-18 Replaced memory addresses for paths and commands to global arrays. Fixed bug where shell would hang if a unknown command is 16 or more chars long. Created arrays and defines for cmd history in shell
    [BDOS.c]
2021-12-19 Added done command in SPI flasher
2021-12-20 reserved socket 7 for netHID (only affects webserv.c). Cleaned code of fs.c in BDOS. also, last commit I forgot to mention that I changed the BDOS_TEMP addr
2021-12-23 New netloader session handler which is less likely to fail. Updated the netflash and netupload scripts as well. Added some parameter checking to send and upload scripts as well
    [BDOS.c, netFlash.py, netUpload.py]
2022-01-12 Basic working version of text editor done. Can now write C code, compile C code and assemble it into a working program, all done on the FPGC itself!
2022-01-12 Added retries to netUpload/Flash.py. Created script that sends all userBDOS files to FPGC. Made seperate script to send single commands to BDOS. Had to add an echo in HIDloader for commands to know w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
